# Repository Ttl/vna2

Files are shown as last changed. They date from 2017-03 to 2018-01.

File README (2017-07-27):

Second version of the homemade 30 MHZ - 6 GHz single receiver VNA design files.

First version: https://github.com/Ttl/vna

For more information see: http://hforsten.com/improved-homemade-vna.html

FPGA can be programmed with Openocd (http://openocd.org/). Scripts for programming the FPGA and SPI flash are in the "openocd" folder. Copy the bit file to openocd folder and use the command "openocd -f <script.cfg>" to program the board.

Before communication is possible with the board through USB, FT2232D EEPROM needs to be programmed. Port B needs to be changed in FIFO 245 mode. This can be done using FTDIs "ft-prog" tool.

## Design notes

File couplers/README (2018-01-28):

Resistive bridge coupler design files.

PCB Stackup: OSH park 4 layer process.

BOM: 
 3, http://www.mouser.fi/ProductDetail/Linx-Technologies/CONSMA003062/?qs=sGAEpiMZZMsgSGrx0WqTbDECK3OTA0n%2f
 1, http://www.mouser.fi/ProductDetail/EPCOS-TDK/B64290P0687X046/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
 3, http://www.mouser.fi/ProductDetail/Fair-Rite/5943000911/?qs=sGAEpiMZZMsuct6UGZJC7QQ6ZlEn2BkEKxrVH5WSvu8%3d
 2, http://www.mouser.fi/ProductDetail/Fair-Rite/5977000101/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

Resistors (See coupler_layout.png for positions):
 R1: 270
 R2: 50
 R3, R5: 36
 R4, R6: 39

Mount the resistors upside down to minimize parasitics.

Coaxial cable:
 RG405

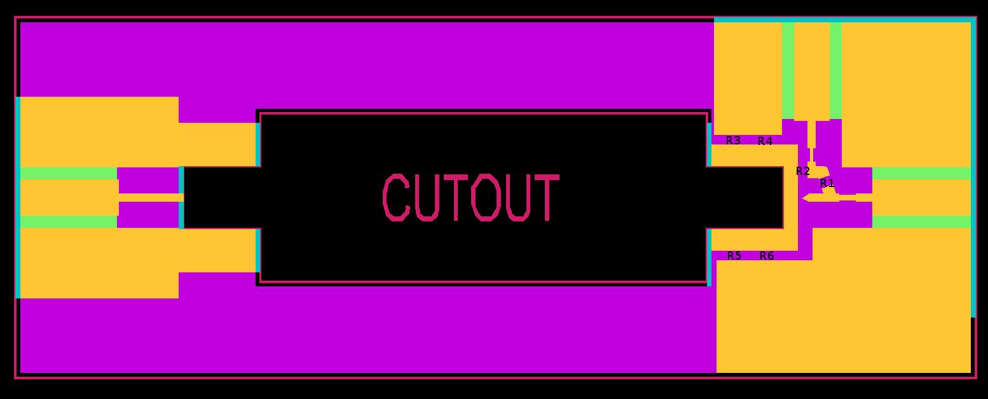
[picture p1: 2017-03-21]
couplers/coupler_layout.png

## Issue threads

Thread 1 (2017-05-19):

Do you have the BOM for VNA2

xfce, 2017-05-19:
Dear friend, do you have the BOM for VNA2, could you please upload here, thanks

Ttl, 2017-05-23:
You can use KiCad to generate BOM. I don't have a more detailed BOM than that at the moment.

Closed 2017-05-23.

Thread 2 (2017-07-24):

reproduction

drom, 2017-07-24:
Hi Henrik,
I am impressed by your VNA design, and want to made one for myself.
Do you recommend any improvements over what you have on Github?
You mentioned:
> The board had unfortunate resonance at 4.2 GHz, which I think comes from the poor grounding of the multiple ground planes. I think I'll need to order a new PCB with better grounding.

Do you plan making new revision of the PCB?

Ttl, 2017-07-24:
Better isolation is the biggest one. Source needs to be shielded and the whole thing needs a case. 5V rail should also have LDO after the buck converter to clean switching noise.

I'm not planning to make a version of the VNA at the moment. Maybe someday in future when I have motivation, but this version works fine enough for now.

The resonance refers to the TRL test board not VNA PCB. I have already made a new version of the test board which works fine.

jsr38, 2017-07-24:
Hey @drom  - I was thinking of building one too.  Sounds like straightforward changes.  I'm not planning on doing it right now but in a few months, when I get some time and my test gear back.  It would be good to share any design changes and progress.

ReinierG, 2017-07-24:
Same here. Time is the biggest issue. I would like to join you. I don't
mind the extra cost of better components (switches, shielding cans,
wider range VCO, ...)

Op 24-7-2017 om 22:45 schreef Jeremy Reeve:
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

oe2lsp, 2017-07-24:
that’s really great :)
I'm planing to build one as well. For shielding maybe for testing a simple Cu-FR4 shield is enough.
There are two improvements I'm thinking about, the first one is a shield around the generator at the top right. As well as some additional vias. I don't know if it is possible to hide a 5V LDO in the current shape, this would be nice so that everyone can use the same milled shield, if we find one.

drom, 2017-07-24:
Great to hear that I am not alone.
@Ttl agree that extra LDO is good.
@Ttl @oe2lsp I am all for more ground, more vias, Cu shielding. Don't mind bigger total PCB area, bit with better ground.
Milled RF shield, sound's expensive, but designing common bended RF shield sounds great

Ttl, 2017-07-25:
Similar sheet metal shielding as with the receiver is not really good enough unless it is soldered all the way such that there are absolutely no gaps at all but that makes prototyping very hard. Of course any shield is better than nothing, but even -100 dB leakage can be detect and a shield with gaps radiates better than that.

I was thinking of separating source and receiver to their own PCBs and connecting the RF with SMA cables. Physical separation is good for improving isolation. Unfortunately all the separate PCBs, shielding, cases and connectors really increase the cost, which is why I haven't had the motivation to make a new version yet.

Also some other improvements that I had in mind:

* Make IF amplifier gain variable (at least 20 dB). Amplifier gain drops at high frequencies and the signal power is much smaller than at low frequencies. Because of that ADC range is not utilized fully and the dynamic range is smaller.
* Replace ADA4932-1 IF amplifier with for example ADA4940-1. The current amplifier doesn't have rail-to-rail outputs and at the maximum output voltage it's close to the limit and causes distortion.
* Duplicate the receivers. One receiver for each port to improve the isolation. This also doubles the measurement speed.

vrytikov, 2017-07-25:
This is a great project. I am thinking of building one too. Would be nice to get pcb improvement.

ReinierG, 2017-07-25:
Hi Henrik,

What about using the recently introduced LMX2594? It has a 10 MHz- 15
GHz range and integrated LDOs. It will be difficult to make good
calibration standards. I've never had a use case for frequencies above
2.4 GHz, but the improved time domain transformation resolution would be
a big plus.
I agree with you about separating parts and connecting with SMA cables.
Modular design make things easier to make improvements. That's how I
started my VNA design (and did not yet finish it...)

Op 25-7-2017 om 07:24 schreef Henrik Forstén:
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

Ttl, 2017-07-25:
There are some issues with using LMX2594. First is that the chip costs 56€ compared to just 10€ for MAX2871. Second is that amplifier, switches and mixer needs to be replaced with 10 GHz capable ones. Those are going to cost also much more than the current ones. Total cost for 10 GHz version would be more than twice of the current version.

drom, 2017-07-25:
@Ttl agree, changing to LMX2594 (15GHz, $63) or even LMX2592 (10GHz, $35) will drive the rest of BOM up.

drom, 2017-07-25:
@Ttl how about replacing monster BGA FPGA package with something like Lattice IC40 Ultra Plus (in 48QFN package): file:///home/drom/work/github/drom/iCE40%20UltraPlus%20Family%20Data%20Sheet.pdf
It has 39 IO, 1Mibit SRAM, 8 MULT16,... etc.

Ttl, 2017-07-26:
ICE40 might have enough gates, but 39 IO pins is not enough. At least 60 pins are needed.

jsr38, 2017-07-26:
Perhaps if there is sufficient demand/activity there is a case for creating individual tickets concerning each proposed change or improvement.  Perhaps there is even a case for a cut-down version and a version where cost is less of a constraint.  Maybe that's a separate project altogether.

On the topic of shielding, would a milled shield be better for prototyping activities?  I don't have practical experience of such things but intuition tells me one should be able to remove and replace such a shield a large number of times if it were bolted.  I guess that would also require something like a fingerstrip to make good contiguous contact with the ground-plane on the board.  Although it sounds expensive perhaps prototyping of the shield could be done with a hobby 3d printer to validate the design before sending the job to a machinist then if there is sufficient interest split the cost of multiple shields to amortise the setup cost.

Actually, over the next few months I am working on modelling the properties of thermoplastic coated with graphite and then electroplated.  Maybe it's good enough to use for prototyping the shielding proper.  Maybe not.

kapil-iitk, 2019-04-18:
I have few to suggestions,
1. Integrate the coupler within the VNA PCB to save few bucks from 6+ 6=12 SMA connectors, and cables.
2. Use copper tape for the shilding. Also add insulator patch (such as OHP sheet) above the circuit (to isolate from the DC short). This may be efficient for the prototyping.

3. Any alternate of FPGA? to reduce the complexity and assembling inaccuracy.

blackberryer, 2019-11-25:
Hi Henrik,
You mentioned:
The resonance refers to the TRL test board not VNA PCB. I have already made a new version of the test board which works fine.

I guess your first version of the TRL test board didn't have enough vias. Is your new board improved grounding by punching enough holes?Is there any improvement elsewhere?

Closed 2017-07-24.

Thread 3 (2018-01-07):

Questions

reliable-bam, 2018-01-07:
First of all, amazing work! I would like to try my hand at cloning this project, and seeing what I can do to increase the frequency range and/or extend to 4 ports. I am in electronics reliability, and often need cheap relatively-accurate RF bench test and in situ (environmental stress) test equipment in the L, S, X, and K bands. Due to business accounting, it's often easier to build engineering boards rather than slug through the arduous capital acquisition steps for equipment that is far more than what I need. My most recent activity requires a stable differential S-par characterization pre/post stress up to 26.5GHz. Obviously I'm not going to get that all in one shot/design/project, and will require an iterative and more complex (and higher part count) solution. This would try to rival the basic capabilities of something like the 5242 4-port PNAs from Keysight/Agilent. If this could be done at 5-10% of the cost, that would be a phenomenal achievement. I would then probably quit my job and make PNA's for a living :-) I think a more reasonable goal would be to target something functional through X band. Any block diagram / recommendations on where to focus for this project would be greatly appreciated. One idea I was thinking about was replacing the baluns with diplexers or filters. This would be much more lossy (particularly in the cross over region) and noisy, but might start me on the path of combining dedicated blocks to handle lower and higher frequency bands without having to source extremely broad band components. As a side note, I'm also aware that calibrating such a beast will be a wholly new project (perhaps a second switched calibration board). I do fully admit that the convenience of Agilent Ecal may be giving me a false impression of how achievable this endevor is.

Also, I had some questions about possible ways to improve performance / noise on your mark-2 VNA design. It seems to me that there is a lot of unused space on the bottom layer. Would it be more efficient to move components that generate noise interference such as receivers/switches to the backside? My thinking is that the internal ground planes should provide some free receiver shielding from the source components and FPGA. Also, this might shorten some of your lines, or place via rows in between some signal lines that are the worst cross-talk offenders (if known). Clearly this would make soldering more of a challenge, but the benefits might outweigh the assy challenges. I was also wondering if you couldn't extend the edge of the board and place the couplers on it? You could pull back the copper grounds for better isolation, and it would cut down on the connectors. The ferrite bead sub assembly is hand solder regardless, and it's one less setup / board fab cost.

Thank you for putting so much effort into making this concept such a successful reality. I'm new to GitHub, and just thrilled that you are sharing the fruits of your labor to perpetuate greater access to advanced analysis tools.

Ttl, 2018-01-09:
It's usually better to use switches and separate circuits for each band than to try designing one very wideband circuit. I don't think there is any place for a diplexer in VNA since it can be replaced with just a switch because there is only one frequency in the circuit at a time.

I wouldn't put components on the back side. It's hard to solder and doesn't improve isolation that much. Better to use individually shielded compartments or separate PCBs.

Connectors don't cost much and it's cheaper to use separate couplers when they are identical than make one big PCB with multiple copies of couplers.

Also take look at #2 for some other possible improvements.

Closed 2018-01-09.

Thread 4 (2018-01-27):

Coupler BOM do not match photos on the blog

micovo, 2018-01-27:
Hi Henrik,
I'm little confused about the difference between coupler BOM on Github and photos on your blog.
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
What I see on the photo is 3pcs of 5943000911, 2pcs of 5977000101 and 1pcs of B64290P0687X046.
On the BOM is 2pcs of 5943000911 and 3pcs of 5977000101.
Did You make a change in assembly without posting it on your blog or is it mistake in the BOM?
Thanks, Michal

Ttl, 2018-01-28:
You're right. I fixed the BOM.

The exact choice of ferrite beads doesn't seem too important. I ran out of some beads and put some different ones in few couplers, but I didn't really notice any significant performance differences.

Closed 2018-01-28.

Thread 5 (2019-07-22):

I and Q data to S parameters algorithm

vijaykarthik123, 2019-07-22:
Hi Henrik,

Great job on the VNA design! I am trying to correlate between an FMCW radar and a VNA. In the FMCW radar, the ADC digitizes the IF signal into I and Q samples.

In your VNA design, the ADC samples the IF signal into I and Q samples. How did you convert the low frequency IF data into RF S parameters? I am reading your `sparam.py` file and in `iq_to_sparam()` there is a formula and algorithm which I am not able to grasp.

Thanks for your help on this.

Ttl, 2019-07-23:
VNA mixes the RF to low frequency IF (few MHz) which is sampled by the ADC and is then IQ mixed inside the FPGA in the digital domain. It needs to be done digitally because analog IQ mixing accuracy isn't high enough.

S-parameters from IQ samples is just normal ratios from the S-parameter definitions. For example S11 is reflected power measurement divided by transmitted power measurement. `sw_correction` in `iq_to_sparam()` is switch correction. It's a part of 8-term VNA calibration.

Closed 2019-07-23.

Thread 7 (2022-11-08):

Cheap shielding

mordae, 2022-11-08:
Hi, thanks for sharing!

I have read your articles and hopefully one day I'll be able to replicate your work.

Wouldn't it be possible to implement shielding cheaper than custom milling / bending with the help of 3D printed covers coated with EMI-shielding copper-based spray paint? There are several products specifically for this use and I have seem them claim about 60 dB attenuation for 50 µm coating.

reliable-bam, 2022-11-08:
Be careful with what you spray over the top of PWBs. Any coating can reduce
switch isolation and introduce coupling. Especially as circuits are in
close proximity.

On Tue, Nov 8, 2022, 4:58 AM Jan Hamal Dvořák ***@***.***>
wrote:

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

mordae, 2022-11-14:
@reliable-bam: I am not sure I follow. I was talking about 3D printing covers (such as those that are usually made from bent metals and soldered on the board - over the components) and coating those. They would have to be mounted using screws instead of being soldered directly, though.

Closed 2024-10-01.

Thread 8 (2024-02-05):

Impedance Problems

kleeneee, 2024-02-05:
Thanks for sharing! From the PCB, I have got the impedances in bridge parts are different and  not equal to 50ohm. Could you please explain the reasons for me? Thank you!

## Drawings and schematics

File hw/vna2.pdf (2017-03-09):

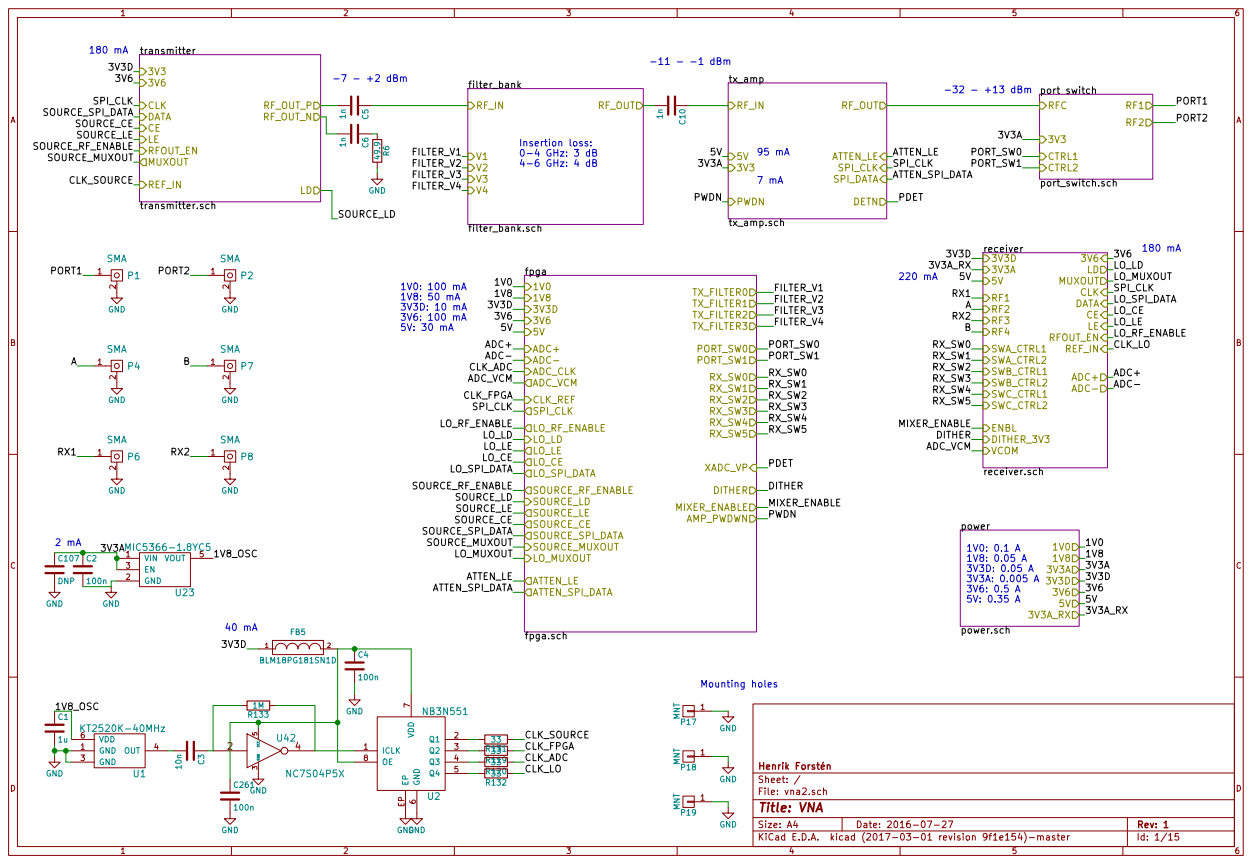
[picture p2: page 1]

File: vna2.sch Sheet: / Henrik Forstén

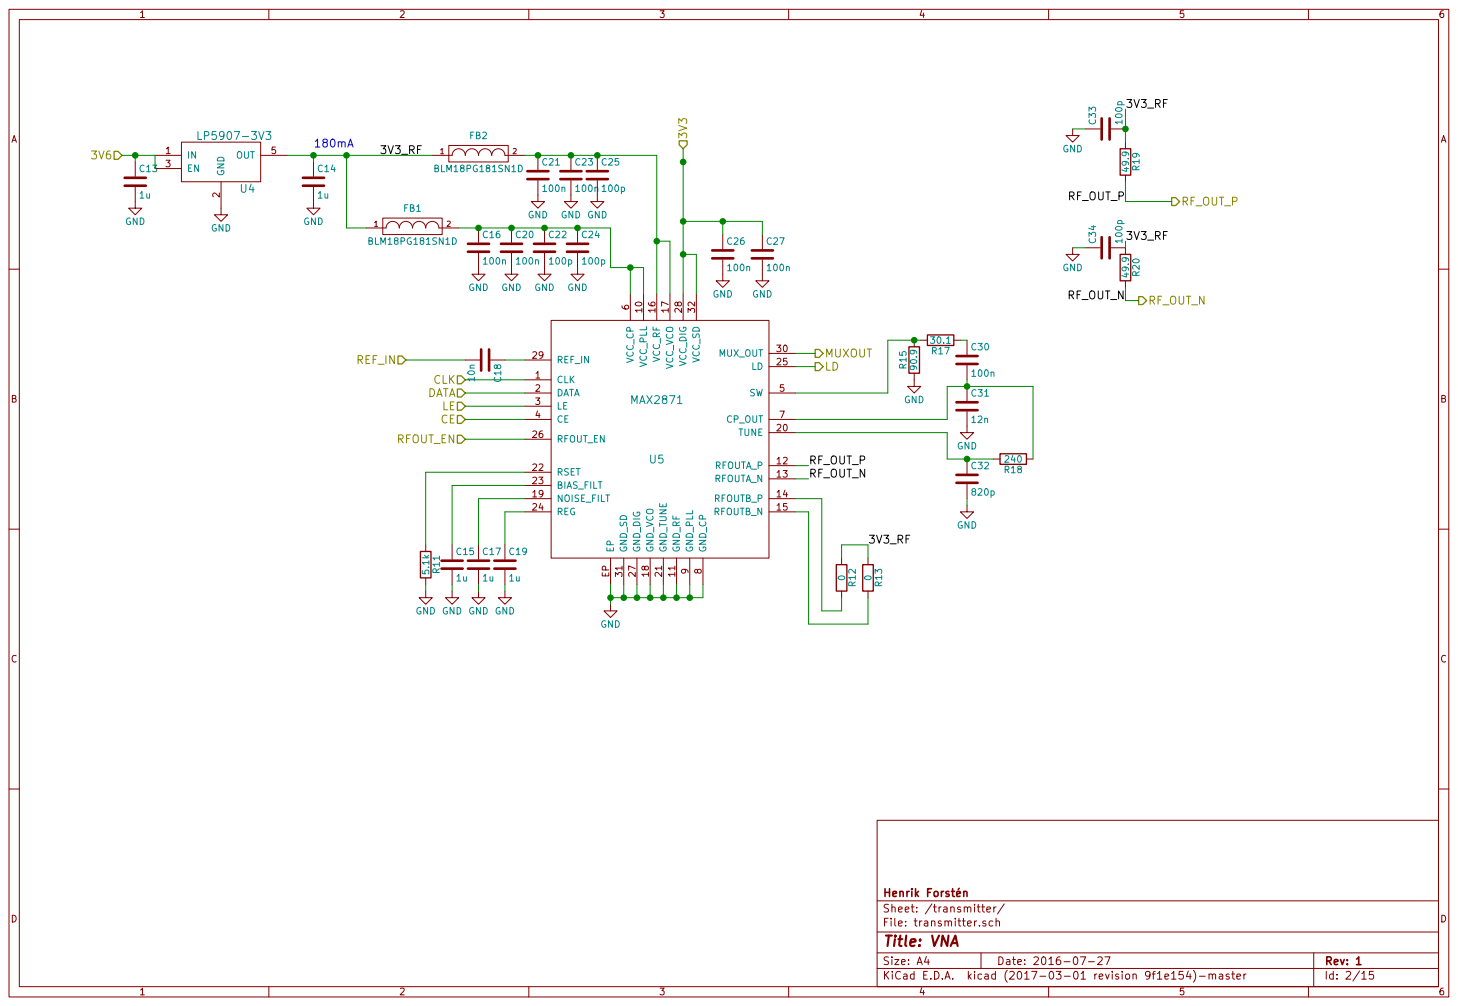
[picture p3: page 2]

100n GND GND GND GND GND

100n 5.1k R11 GND GND GND GND

File: transmitter.sch Sheet: /transmitter/ Henrik Forstén

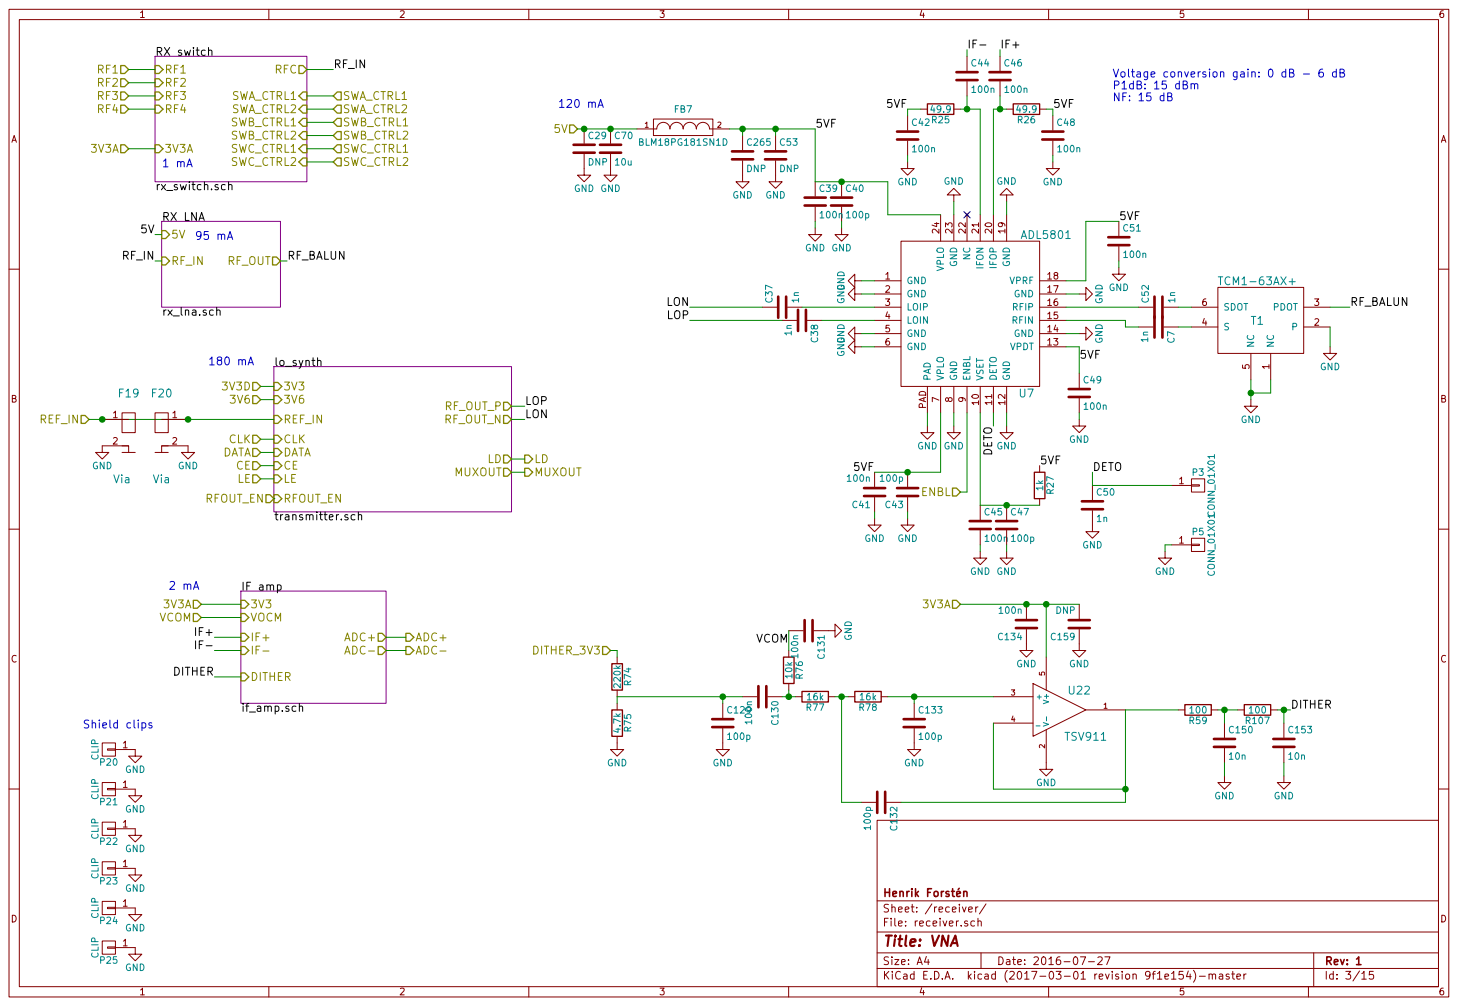
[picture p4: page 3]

9 VSET 10 IFOP 20 DETO 11 IFON 21 GND 12 NC 22 VPDT 13 GND 23 GND 14 VPLO 24 RFIN 15 RFIP 16 GND 17 VPRF 18 GND 19 PAD PADU7ADL5801 GND GND C37 1n

File: receiver.sch Sheet: /receiver/ Henrik Forstén

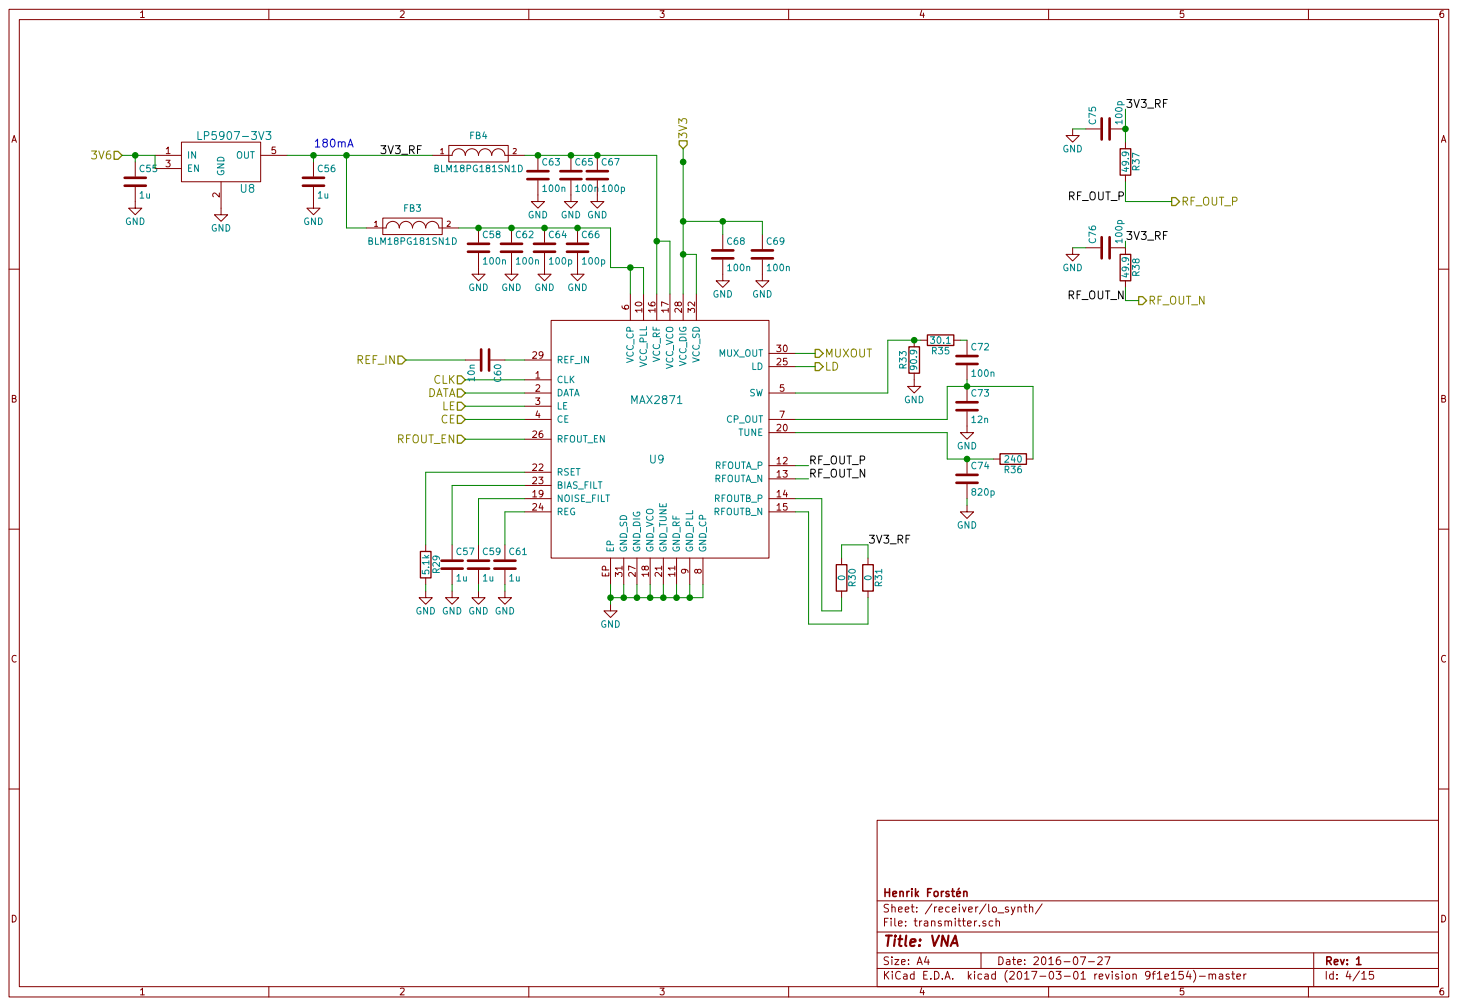
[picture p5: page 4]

100n GND GND GND GND GND

100n 5.1k R29 GND GND GND GND

Henrik Forstén
File: transmitter.sch Sheet: /receiver/lo_synth/
Id: 4/15 Title: VNA

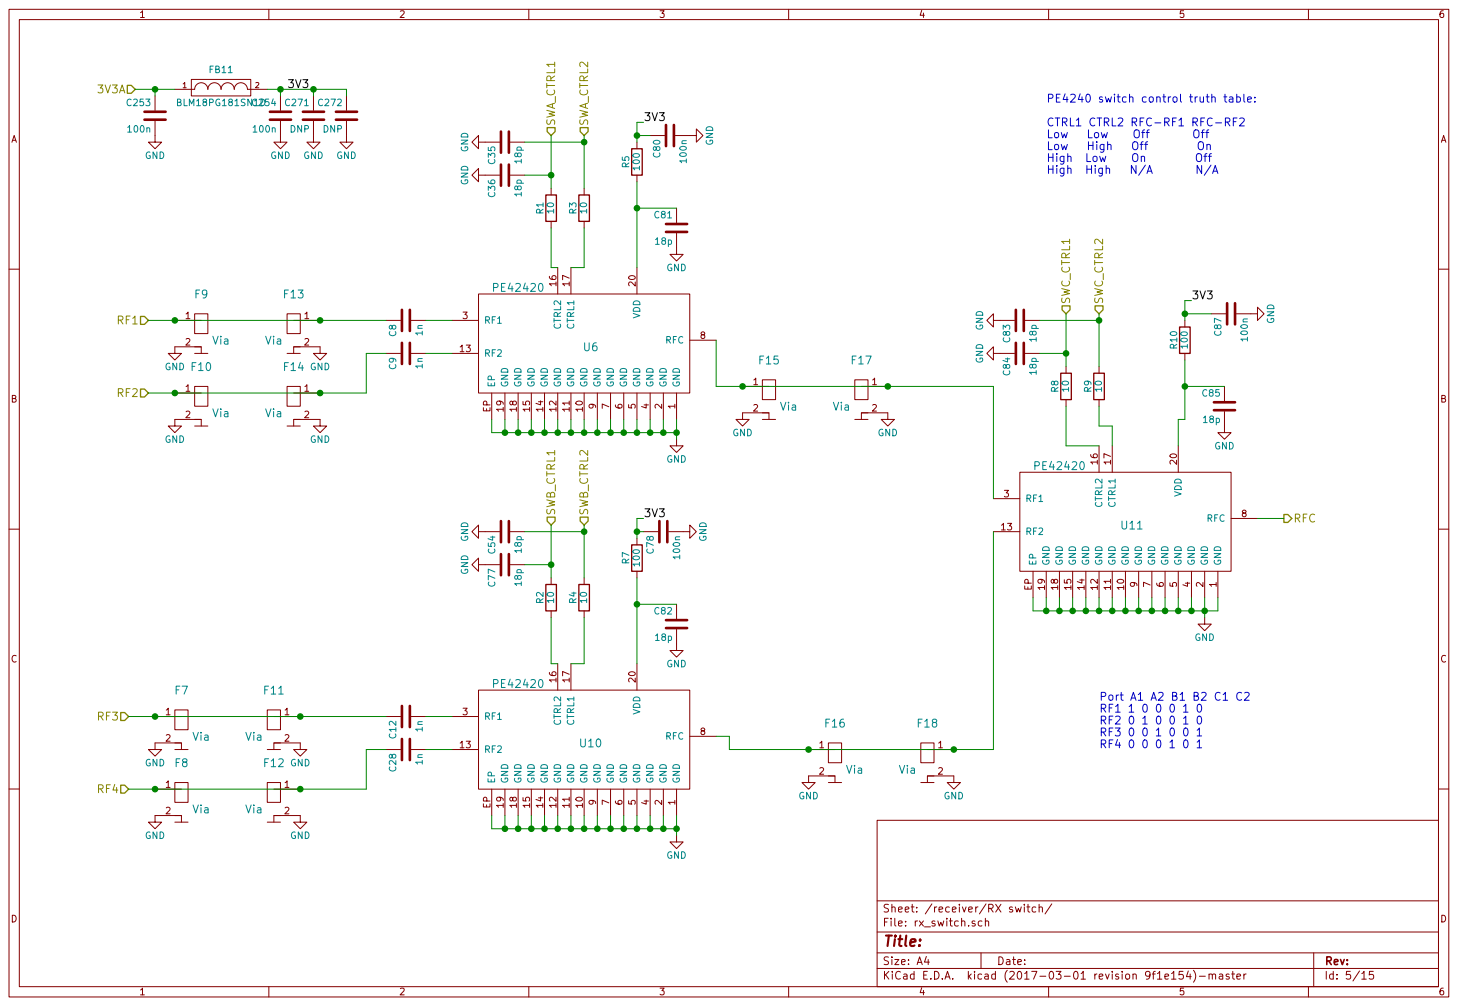
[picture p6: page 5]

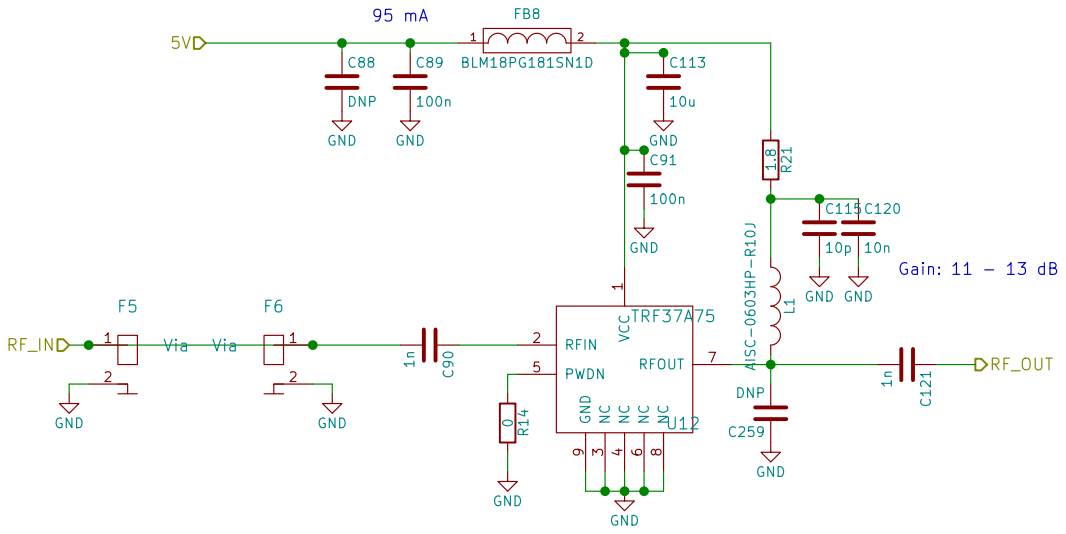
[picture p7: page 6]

File: rx_lna.sch Sheet: /receiver/RX LNA/ VCC

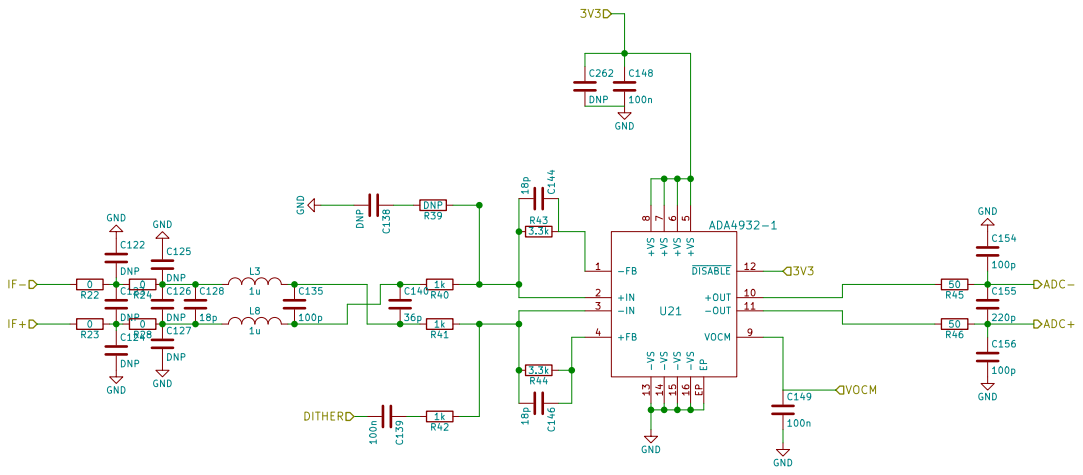
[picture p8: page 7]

C125 DNP C127 DNP GND GND

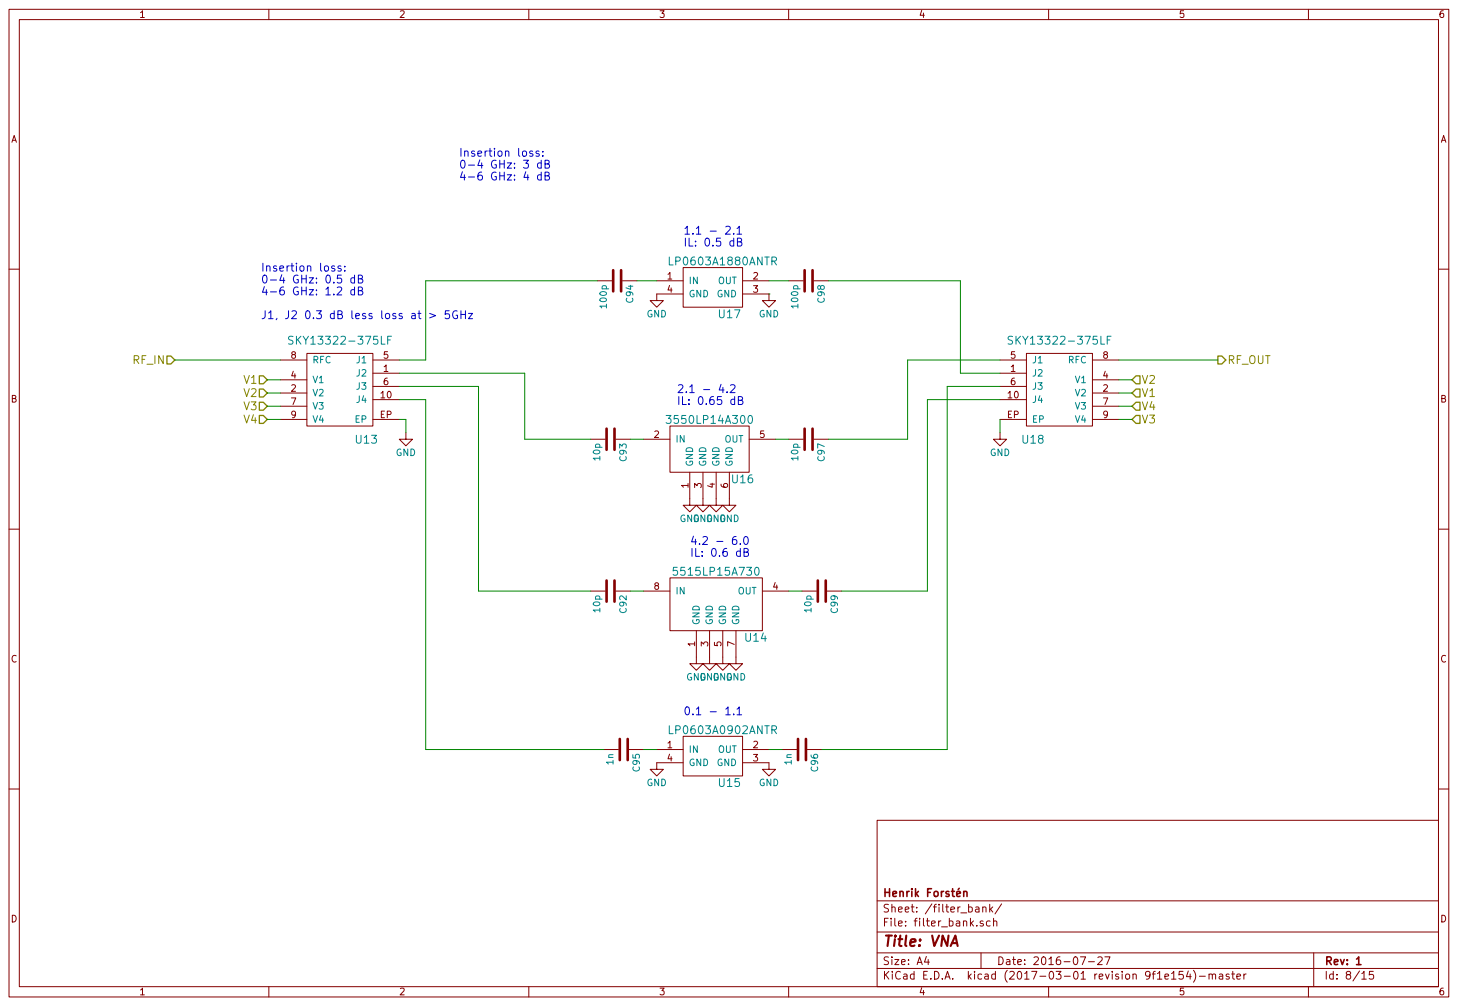
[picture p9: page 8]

Insertion loss: 0-4 GHz: 3 dB
4-6 GHz: 4 dB

Insertion loss: 0-4 GHz: 0.5 dB
4-6 GHz: 1.2 dB
J1, J2 0.3 dB less loss at > 5GHz

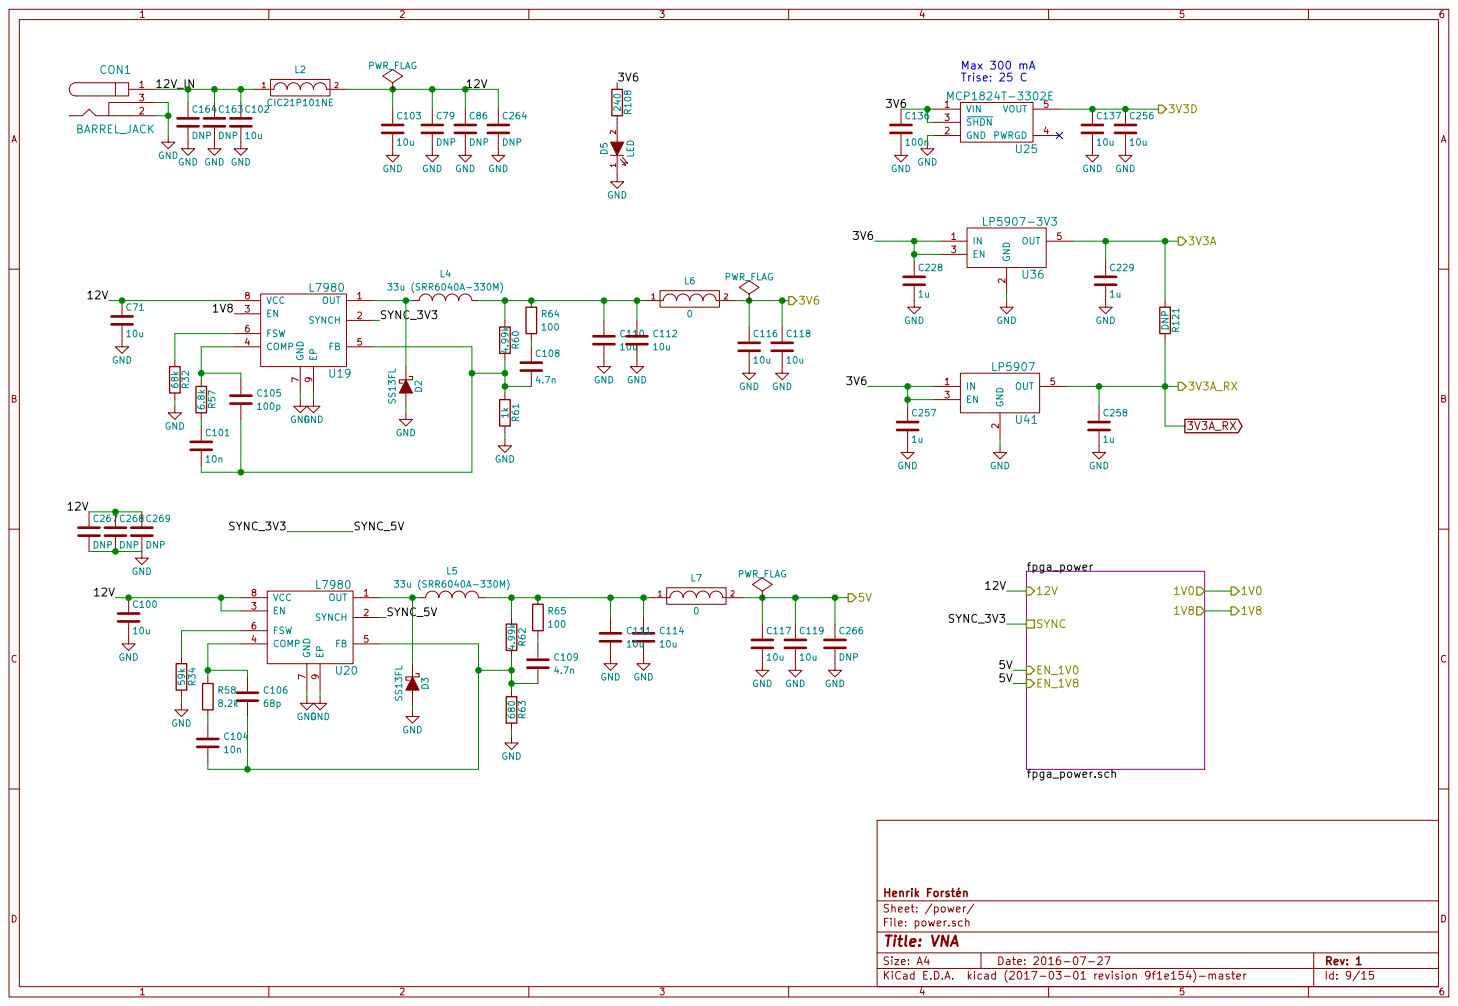
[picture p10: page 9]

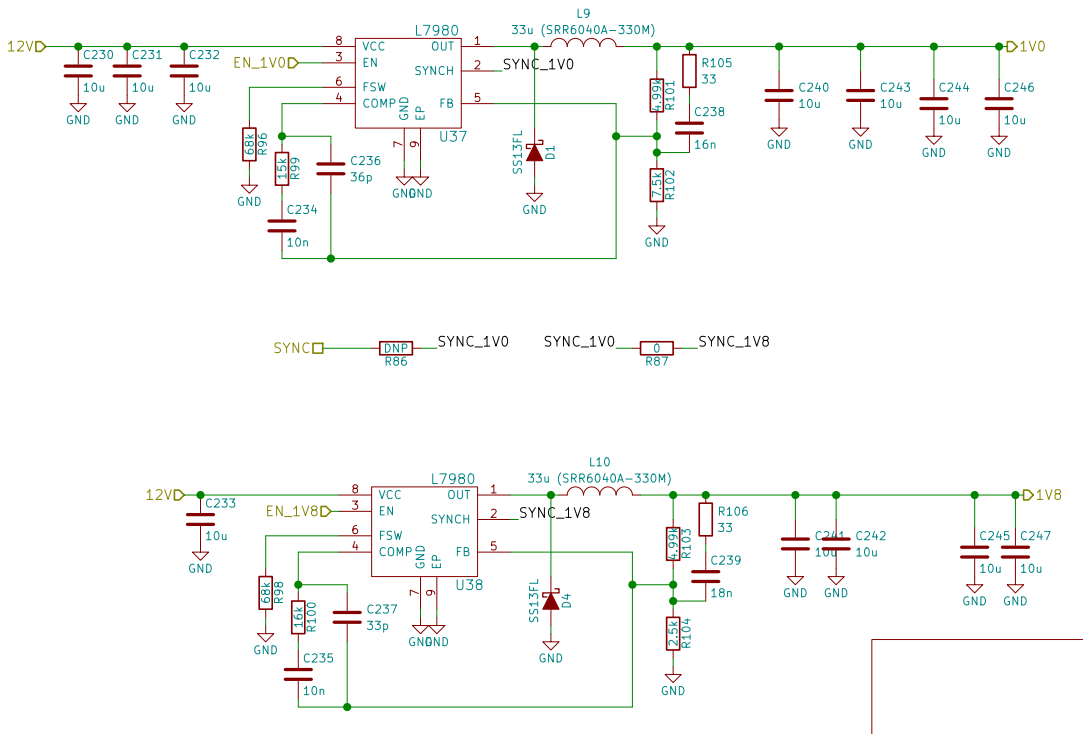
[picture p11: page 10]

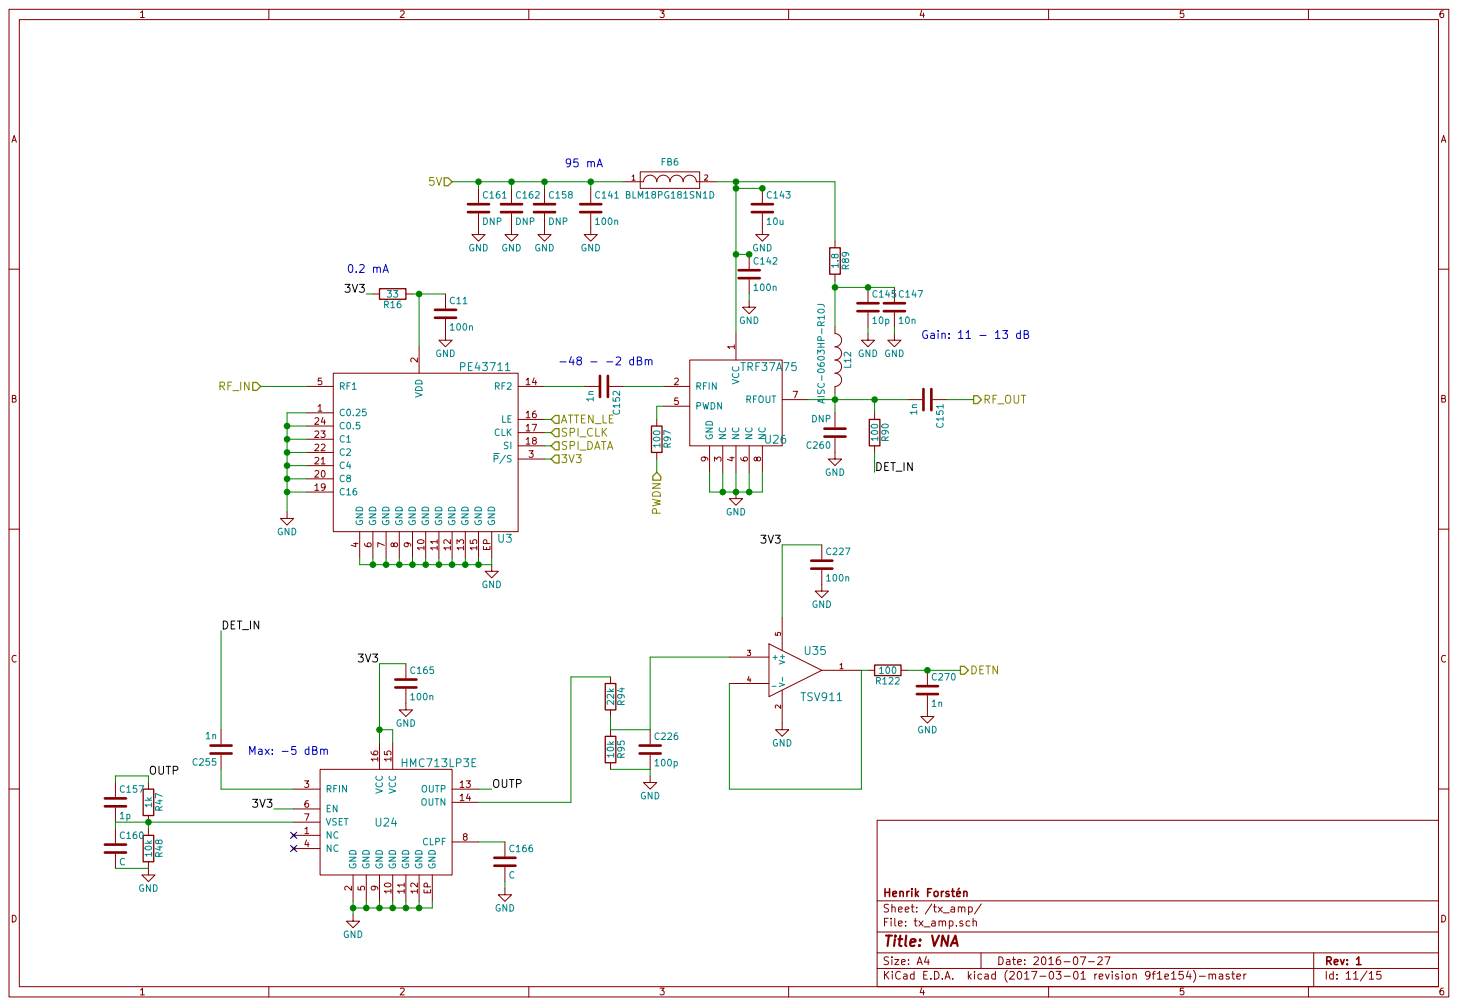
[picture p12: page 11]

9 GND 10 C8 20 GND 11 C4 21 GND 12 C2 22 GND 13 C1 23 RF2 14 C0.5 24 GND 15

9 GND 10 GND 11 GND 12 OUTP 13 OUTN 14 VCC 15 VCC 16 GND EP U24 HMC713LP3E

5 EN 6 VSET 7 CLPF 8 GND

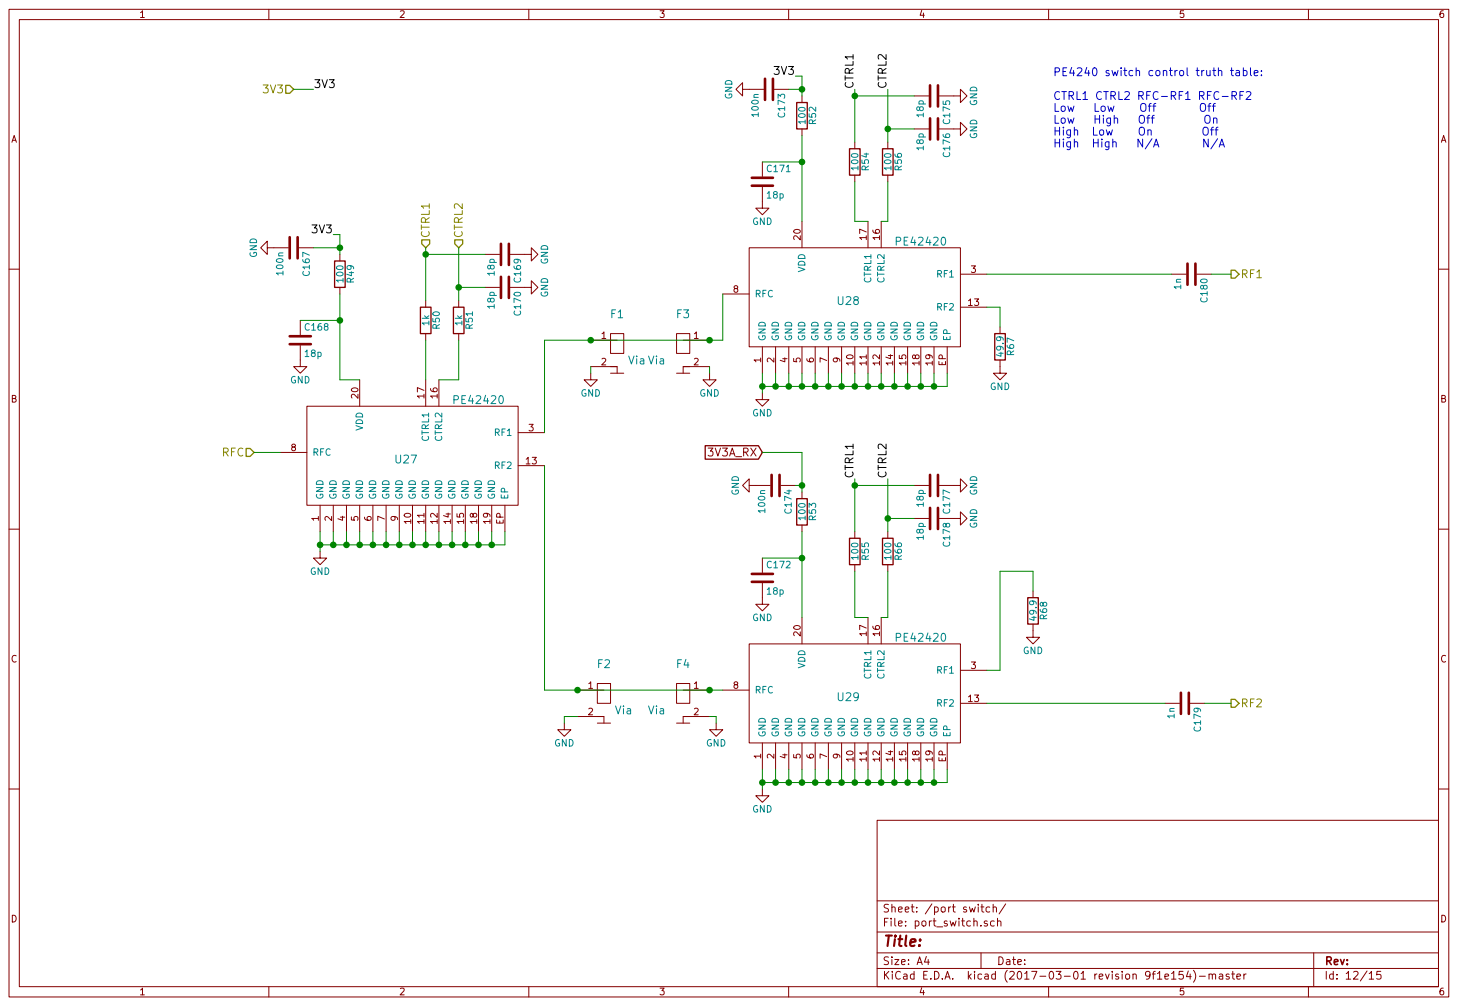
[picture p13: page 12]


adc adc.sch ADC+

Power supply ramp time: 0.2 ms - 50 ms
Internal reference Quiescent current 1V0: 97 mA

Power-on current 1V0: Iq + 180 mA


TMS D0 D1 D2 D3 D4 D5 D6 D7 RXF# TXE# RD# WR

9 SI/WUA 10 ADBUS4 20 BCBUS0/RXF# 30 BDBUS0 40 ACBUS3 11 ADBUS3/TMS 21 VCCIOB 31 PWREN# 41 ACBUS2 12 ADBUS2/TDO 22 BDBUS7 32 VCC 42 ACBUS1 13 ADBUS1/TDI 23 BDBUS6 33 XTIN 43 VCCIOA 14 ADBUS0/TCK 24 GND 34 XTOUT 44 ACBUS0 15 GND 25 BDBUS5 35 AGND 45 ADBUS7 16 SI/WUB 26 BDBUS4 36 AVCC 46 ADBUS6 17 BCBUS3/WR 27 BDBUS3 37 TEST 47 GND 18 BCBUS2/RD# 28 BDBUS2 38 EECS 48 ADBUS5 19 BCBUS1/TXE# 29 BDBUS1 39 U33 FT2232D


8 CLK 9 SHDN 10 OGND 20 SENSE 30 OE 11 OVDD 21 D0 12 D8 22 VDD 32 D1 13 D9 23 D2 14 D10 24 D3 15 D11 25 D4 16 D12 26 D5 17 D13 27 D6 18 OF 28 D7 19 MODE 29 U34

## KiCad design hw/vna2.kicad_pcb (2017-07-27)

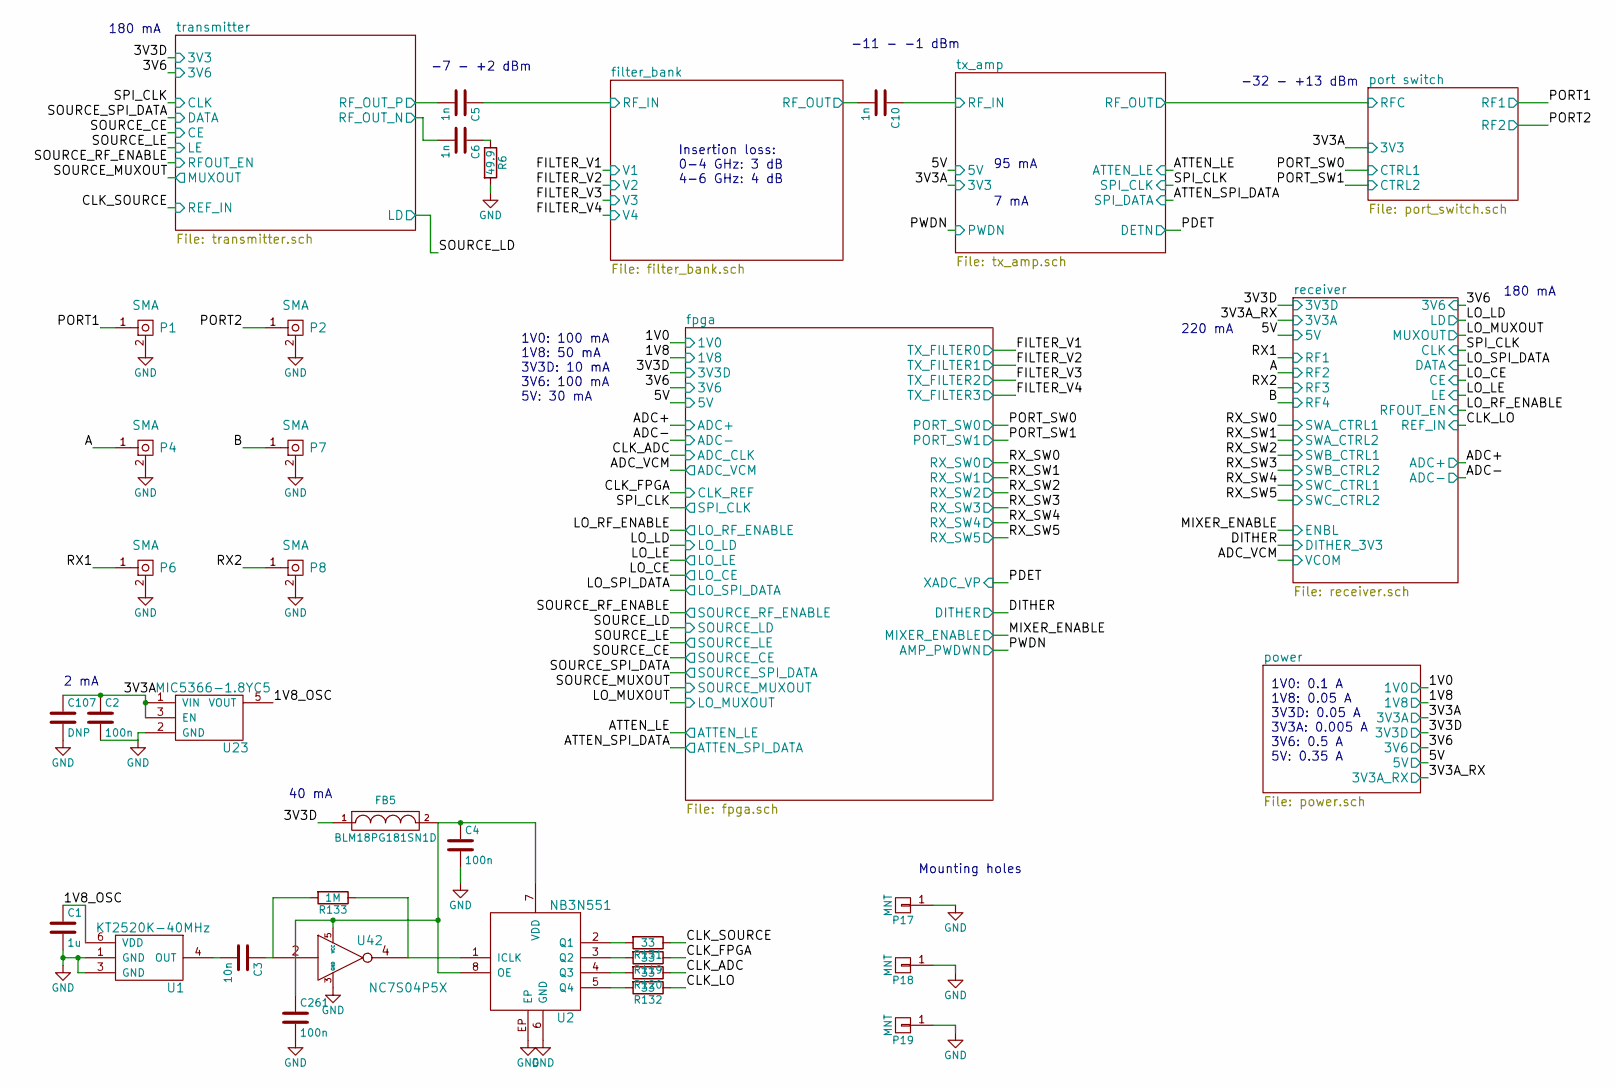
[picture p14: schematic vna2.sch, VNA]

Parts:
C1: 1u; C_0402b
C2, C4, C261: 100n; C_0402b
C3: 10n; C_0402b
C5, C6, C10: 1n; C_0402b
C107: DNP; C_0805b
FB5: BLM18PG181SN1D; C_0603b
P1, P2, P4, P6, P7, P8: SMA; CONSMA003.062
P17, P18, P19: MNT; MountingHole_3.2mm_M3_Pad_Via_mod
R6: 49.9; R_0402b
R119, R120, R131, R132: 33; R_0402b
R133: 1M; R_0402b
U1: KT2520K-40MHz; KT2520K
U2: NB3N551; DFN-8
U23: MIC5366-1.8YC5; SOT-353
U42: NC7S04P5X; SOT-353

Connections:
/1V8_OSC: C1.1, U1.6 (VDD), U23.5 (VOUT)
/3V3A: C2.1, C107.1, U23.1 (VIN), U23.3 (EN); also elsewhere on the board
/3V3D: FB5.1; also elsewhere on the board
/A: P4.1; also elsewhere on the board
/B: P7.1; also elsewhere on the board
/CLK_ADC: R120.1; also elsewhere on the board
/CLK_FPGA: R119.1; also elsewhere on the board
/CLK_LO: R132.1; also elsewhere on the board
/CLK_SOURCE: R131.1; also elsewhere on the board
/PORT1: P1.1; also elsewhere on the board
/PORT2: P2.1; also elsewhere on the board
/RX1: P6.1; also elsewhere on the board
/RX2: P8.1; also elsewhere on the board
/filter_bank/RF_IN: C5.1; also elsewhere on the board
/filter_bank/RF_OUT: C10.2; also elsewhere on the board
/transmitter/RF_OUT_N: C6.2; also elsewhere on the board
/transmitter/RF_OUT_P: C5.2; also elsewhere on the board
/tx_amp/RF_IN: C10.1; also elsewhere on the board
GND: C1.2, C2.2, C4.2, C107.2, C261.2, P1.2, P2.2, P4.2, P6.2, P7.2, P8.2, P17.1, P18.1, P19.1, R6.2, U1.1 (GND), U1.3 (GND), U2.6 (GND), U2.EP, U23.2 (GND), U42.3 (GND); also elsewhere on the board
unnamed: C3.1, R133.2, U42.2
unnamed: C3.2, U1.4 (OUT)
unnamed: C6.1, R6.1
unnamed: C4.1, C261.1, FB5.2, U2.7 (VDD), U2.8 (OE), U42.5 (VCC)
unnamed: R119.2, U2.3 (Q2)
unnamed: R120.2, U2.4 (Q3)
unnamed: R131.2, U2.2 (Q1)
unnamed: R132.2, U2.5 (Q4)
unnamed: R133.1, U2.1 (ICLK), U42.4

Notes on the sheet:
2 mA
Insertion loss: 0-4 GHz: 3 dB 4-6 GHz: 4 dB
-7 - +2 dBm
-11 - -1 dBm
-32 - +13 dBm
180 mA
220 mA
95 mA
7 mA
1V0: 100 mA 1V8: 50 mA 3V3D: 10 mA 3V6: 100 mA 5V: 30 mA
1V0: 0.1 A 1V8: 0.05 A 3V3D: 0.05 A 3V3A: 0.005 A 3V6: 0.5 A 5V: 0.35 A
Mounting holes
40 mA

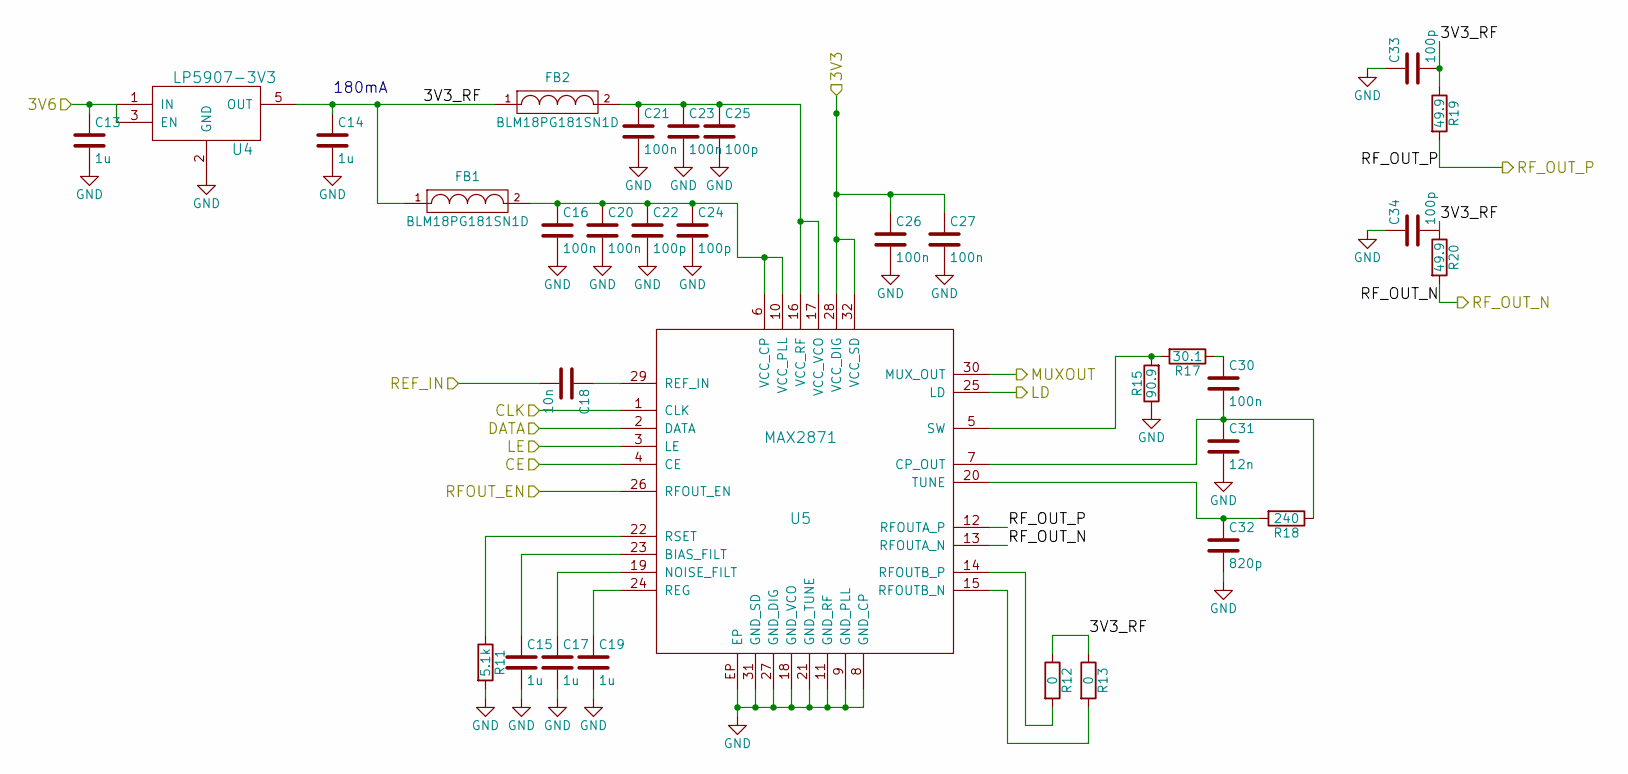
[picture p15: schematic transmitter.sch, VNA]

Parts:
C13, C14, C15, C17, C19: 1u; C_0603b
C16, C20, C21, C23, C26, C27, C30: 100n; C_0402b
C18: 10n; C_0402b
C22, C24, C25, C33, C34: 100p; C_0402b
C31: 12n; C_0402b
C32: 820p; C_0402b
FB1, FB2: BLM18PG181SN1D; C_0603b
R11: 5.1k; R_0402b
R12, R13: 0; R_0402b
R15: 90.9; R_0402b
R17: 30.1; R_0402b
R18: 240; R_0402b
R19, R20: 49.9; R_0402b
U4: LP5907-3V3; SOT-23-5
U5: MAX2871; TQFN-32

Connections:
/3V3D: C26.1, C27.1, U5.28 (VCC_DIG), U5.32 (VCC_SD); also elsewhere on the board
/3V6: C13.1, U4.1 (IN), U4.3 (EN); also elsewhere on the board
/CLK_SOURCE: C18.2; also elsewhere on the board
/SOURCE_CE: U5.4 (CE); also elsewhere on the board
/SOURCE_LD: U5.25 (LD); also elsewhere on the board
/SOURCE_LE: U5.3 (LE); also elsewhere on the board
/SOURCE_MUXOUT: U5.30 (MUX_OUT); also elsewhere on the board
/SOURCE_RF_ENABLE: U5.26 (RFOUT_EN); also elsewhere on the board
/SOURCE_SPI_DATA: U5.2 (DATA); also elsewhere on the board
/SPI_CLK: U5.1 (CLK); also elsewhere on the board
/transmitter/3V3_RF: C14.1, C33.2, C34.2, FB1.1, FB2.1, R12.1, R13.1, R19.1, R20.1, U4.5 (OUT)
/transmitter/RF_OUT_N: R20.2, U5.13 (RFOUTA_N); also elsewhere on the board
/transmitter/RF_OUT_P: R19.2, U5.12 (RFOUTA_P); also elsewhere on the board
GND: C13.2, C14.2, C15.2, C16.2, C17.2, C19.2, C20.2, C21.2, C22.2, C23.2, C24.2, C25.2, C26.2, C27.2, C31.2, C32.2, C33.1, C34.1, R11.2, R15.1, U4.2 (GND), U5.8 (GND_CP), U5.9 (GND_PLL), U5.11 (GND_RF), U5.18 (GND_VCO), U5.21 (GND_TUNE), U5.27 (GND_DIG), U5.31 (GND_SD), U5.EP; also elsewhere on the board
unnamed: C15.1, U5.23 (BIAS_FILT)
unnamed: C16.1, C20.1, C22.1, C24.1, FB1.2, U5.6 (VCC_CP), U5.10 (VCC_PLL)
unnamed: C17.1, U5.19 (NOISE_FILT)
unnamed: C18.1, U5.29 (REF_IN)
unnamed: C19.1, U5.24 (REG)
unnamed: C21.1, C23.1, C25.1, FB2.2, U5.16 (VCC_RF), U5.17 (VCC_VCO)
unnamed: C30.1, R17.1
unnamed: C30.2, C31.1, R18.1, U5.7 (CP_OUT)
unnamed: C32.1, R18.2, U5.20 (TUNE)
unnamed: R11.1, U5.22 (RSET)
unnamed: R12.2, U5.14 (RFOUTB_P)
unnamed: R13.2, U5.15 (RFOUTB_N)
unnamed: R15.2, R17.2, U5.5 (SW)

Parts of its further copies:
C55, C56, C57, C59, C61: 1u; C_0603b
C58, C62, C63, C65, C68, C69, C72: 100n; C_0402b
C60: 10n; C_0402b
C64, C66, C67, C75, C76: 100p; C_0402b
C73: 12n; C_0402b
C74: 820p; C_0402b
FB3, FB4: BLM18PG181SN1D; C_0603b
R29: 5.1k; R_0402b
R30, R31: 0; R_0402b
R33: 90.9; R_0402b
R35: 30.1; R_0402b
R36: 240; R_0402b
R37, R38: 49.9; R_0402b
U8: LP5907-3V3; SOT-23-5
U9: MAX2871; TQFN-32

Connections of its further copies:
/3V3D: C68.1, C69.1, U9.28 (VCC_DIG), U9.32 (VCC_SD); also elsewhere on the board
/3V6: C55.1, U8.1 (IN), U8.3 (EN); also elsewhere on the board
/CLK_LO: C60.2; also elsewhere on the board
/LO_CE: U9.4 (CE); also elsewhere on the board
/LO_LD: U9.25 (LD); also elsewhere on the board
/LO_LE: U9.3 (LE); also elsewhere on the board
/LO_MUXOUT: U9.30 (MUX_OUT); also elsewhere on the board
/LO_RF_ENABLE: U9.26 (RFOUT_EN); also elsewhere on the board
/LO_SPI_DATA: U9.2 (DATA); also elsewhere on the board
/SPI_CLK: U9.1 (CLK); also elsewhere on the board
/receiver/LON: R38.2, U9.13 (RFOUTA_N); also elsewhere on the board
/receiver/LOP: R37.2, U9.12 (RFOUTA_P); also elsewhere on the board
/receiver/lo_synth/3V3_RF: C56.1, C75.2, C76.2, FB3.1, FB4.1, R30.1, R31.1, R37.1, R38.1, U8.5 (OUT)
GND: C55.2, C56.2, C57.2, C58.2, C59.2, C61.2, C62.2, C63.2, C64.2, C65.2, C66.2, C67.2, C68.2, C69.2, C73.2, C74.2, C75.1, C76.1, R29.2, R33.1, U8.2 (GND), U9.8 (GND_CP), U9.9 (GND_PLL), U9.11 (GND_RF), U9.18 (GND_VCO), U9.21 (GND_TUNE), U9.27 (GND_DIG), U9.31 (GND_SD), U9.EP; also elsewhere on the board
unnamed: C57.1, U9.23 (BIAS_FILT)
unnamed: C58.1, C62.1, C64.1, C66.1, FB3.2, U9.6 (VCC_CP), U9.10 (VCC_PLL)
unnamed: C59.1, U9.19 (NOISE_FILT)
unnamed: C60.1, U9.29 (REF_IN)
unnamed: C61.1, U9.24 (REG)
unnamed: C63.1, C65.1, C67.1, FB4.2, U9.16 (VCC_RF), U9.17 (VCC_VCO)
unnamed: C72.1, R35.1
unnamed: C72.2, C73.1, R36.1, U9.7 (CP_OUT)
unnamed: C74.1, R36.2, U9.20 (TUNE)
unnamed: R29.1, U9.22 (RSET)
unnamed: R30.2, U9.14 (RFOUTB_P)
unnamed: R31.2, U9.15 (RFOUTB_N)
unnamed: R33.2, R35.2, U9.5 (SW)

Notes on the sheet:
180mA

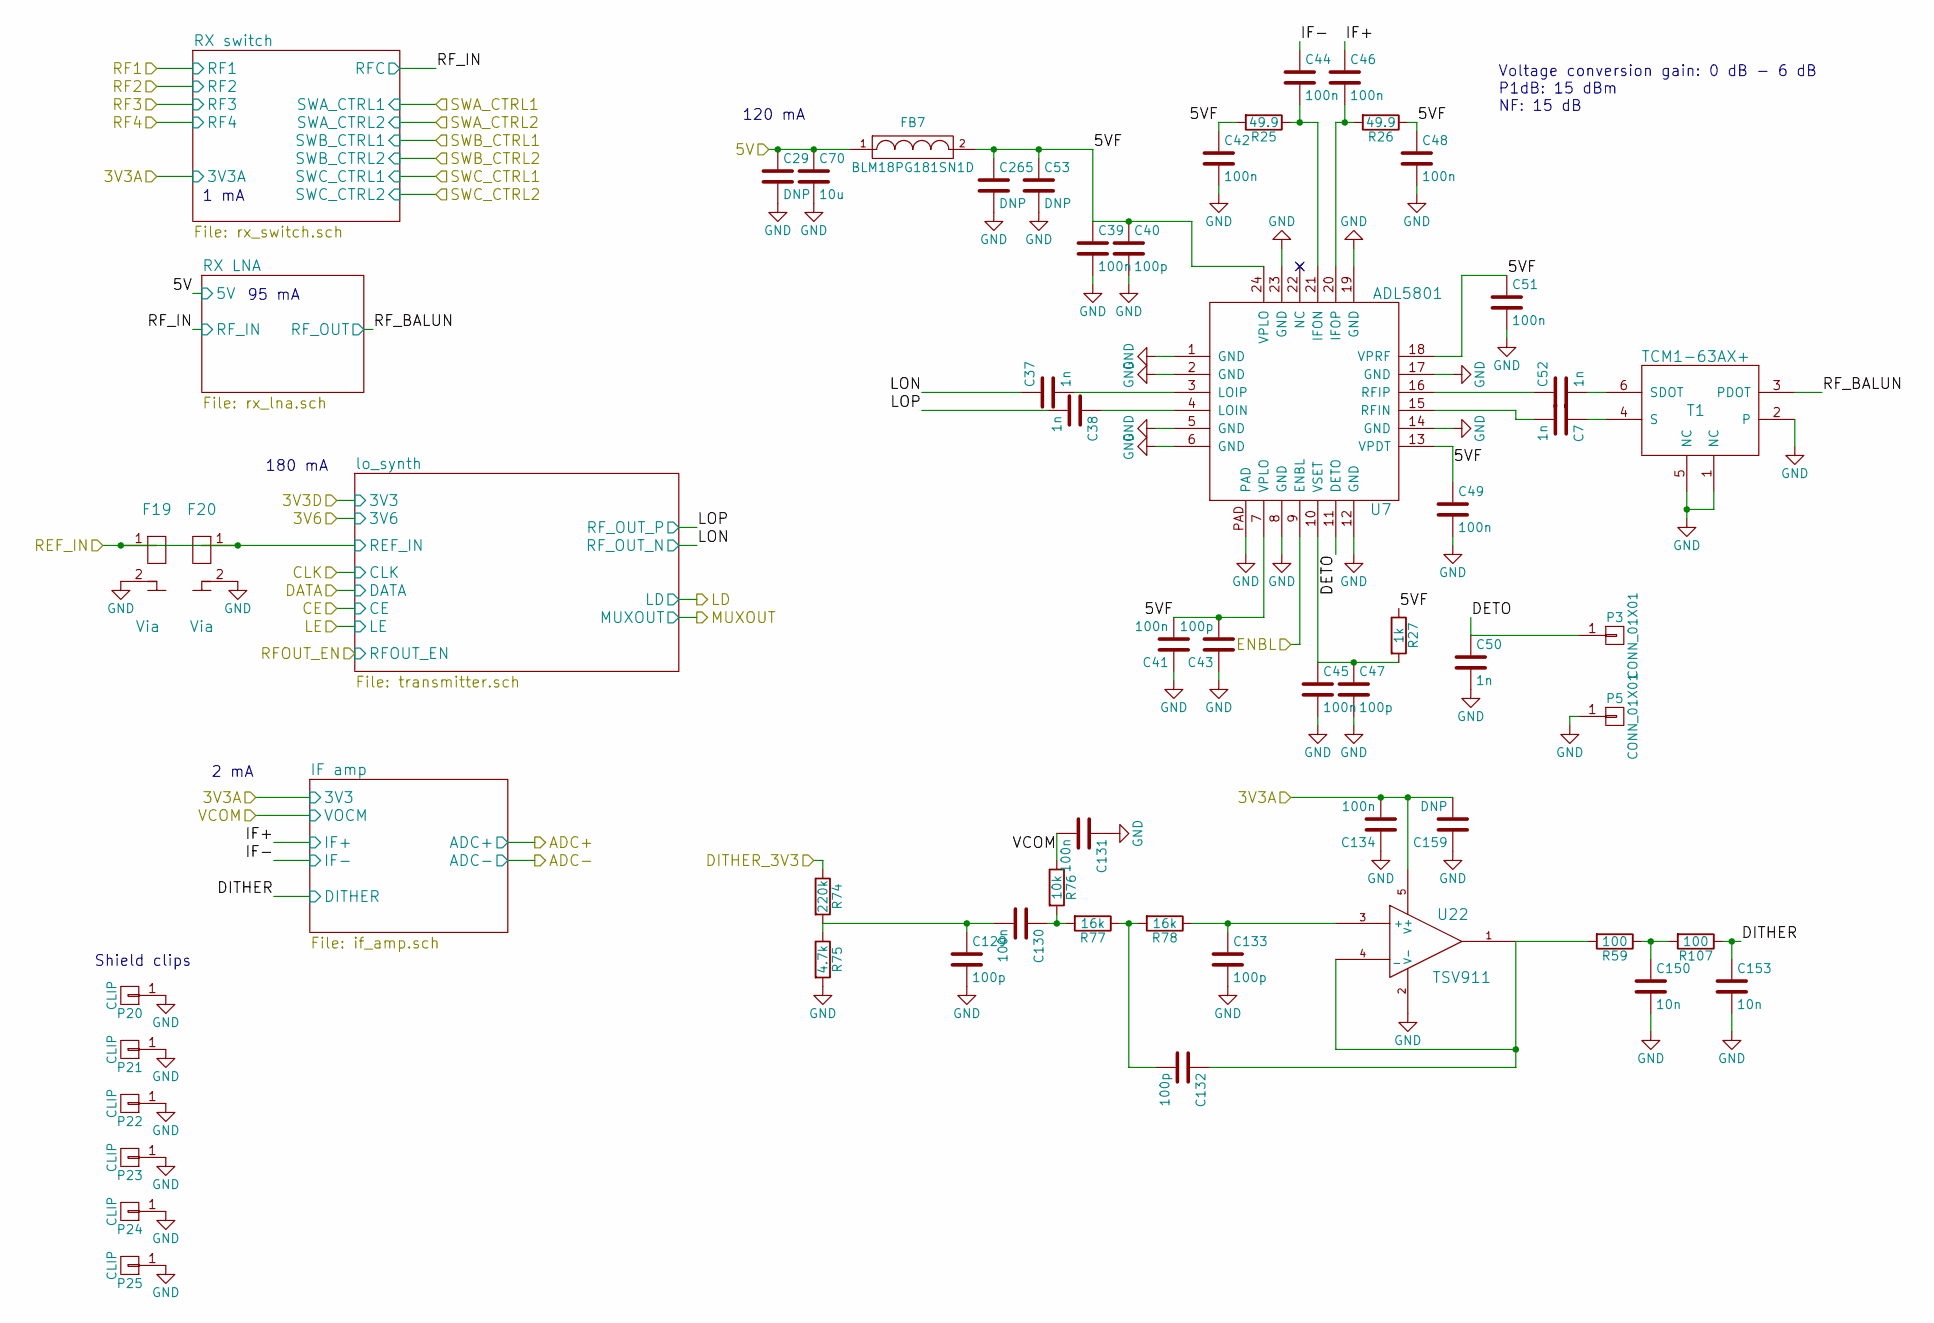
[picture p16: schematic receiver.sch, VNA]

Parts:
C7, C37, C38, C50, C52: 1n; C_0402b
C29: DNP; C_0603b
C39, C41, C42, C44, C45, C46, C48, C49, C51, C130, C131, C134: 100n; C_0402b
C40, C43, C47, C129, C132, C133: 100p; C_0402b
C53, C159, C265: DNP; C_0805b
C70: 10u; C_0805b
C150, C153: 10n; C_0402b
F19, F20: Via; RF_via
FB7: BLM18PG181SN1D; C_0603b
P3, P5: CONN_01X01; TP_1.00
P20, P21, P22, P23, P24, P25: CLIP; S2711-46R
R25, R26: 49.9; R_0402b
R27: 1k; R_0402b
R59, R107: 100; R_0402b
R74: 220k; R_0402b
R75: 4.7k; R_0402b
R76: 10k; R_0402b
R77, R78: 16k; R_0402b
T1: TCM1-63AX+
U7: ADL5801; VFQFN-24
U22: TSV911; SOT-23-5

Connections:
3V3A_RX: C134.2, C159.2, U22.5 (V+); also elsewhere on the board
/5V: C29.1, C70.1, FB7.1; also elsewhere on the board
/ADC_VCM: C131.2, R76.1; also elsewhere on the board
/CLK_LO: F19.1, F20.1; also elsewhere on the board
/DITHER: R74.1; also elsewhere on the board
/MIXER_ENABLE: U7.9 (ENBL); also elsewhere on the board
/receiver/5VF: C39.1, C40.1, C41.2, C42.1, C43.2, C48.1, C49.1, C51.1, C53.1, C265.1, FB7.2, R25.2, R26.1, R27.1, U7.7 (VPLO), U7.13 (VPDT), U7.18 (VPRF), U7.24 (VPLO)
/receiver/DETO: C50.1, P3.1, U7.11 (DETO)
/receiver/DITHER: C153.1, R107.1; also elsewhere on the board
/receiver/IF+: C46.1; also elsewhere on the board
/receiver/IF-: C44.1; also elsewhere on the board
/receiver/LON: C37.1; also elsewhere on the board
/receiver/LOP: C38.2; also elsewhere on the board
/receiver/RF_BALUN: T1.3 (PDOT); also elsewhere on the board
GND: C29.2, C39.2, C40.2, C41.1, C42.2, C43.1, C45.2, C47.2, C48.2, C49.2, C50.2, C51.2, C53.2, C70.2, C129.2, C131.1, C133.2, C134.1, C150.2, C153.2, C159.1, C265.2, F19.2, F20.2, P5.1, P20.1, P21.1, P22.1, P23.1, P24.1, P25.1, R75.2, T1.1 (NC), T1.2, T1.5 (NC), U7.1 (GND), U7.2 (GND), U7.5 (GND), U7.6 (GND), U7.8 (GND), U7.12 (GND), U7.14 (GND), U7.17 (GND), U7.19 (GND), U7.23 (GND), U7.PAD, U22.2 (V-); also elsewhere on the board
unnamed: C7.1, T1.4 (S)
unnamed: C7.2, U7.15 (RFIN)
unnamed: C37.2, U7.3 (LOIP)
unnamed: C38.1, U7.4 (LOIN)
unnamed: C44.2, R25.1, U7.21 (IFON)
unnamed: C45.1, C47.1, R27.2, U7.10 (VSET)
unnamed: C46.2, R26.2, U7.20 (IFOP)
unnamed: C52.1, U7.16 (RFIP)
unnamed: C52.2, T1.6 (SDOT)
unnamed: C129.1, C130.2, R74.2, R75.1
unnamed: C130.1, R76.2, R77.2
unnamed: C132.1, R59.2, U22.1, U22.4 (_)
unnamed: C132.2, R77.1, R78.2
unnamed: C133.1, R78.1, U22.3 (+)
unnamed: C150.1, R59.1, R107.2

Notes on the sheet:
Voltage conversion gain: 0 dB - 6 dB P1dB: 15 dBm NF: 15 dB
120 mA
180 mA
2 mA
Shield clips
1 mA
95 mA

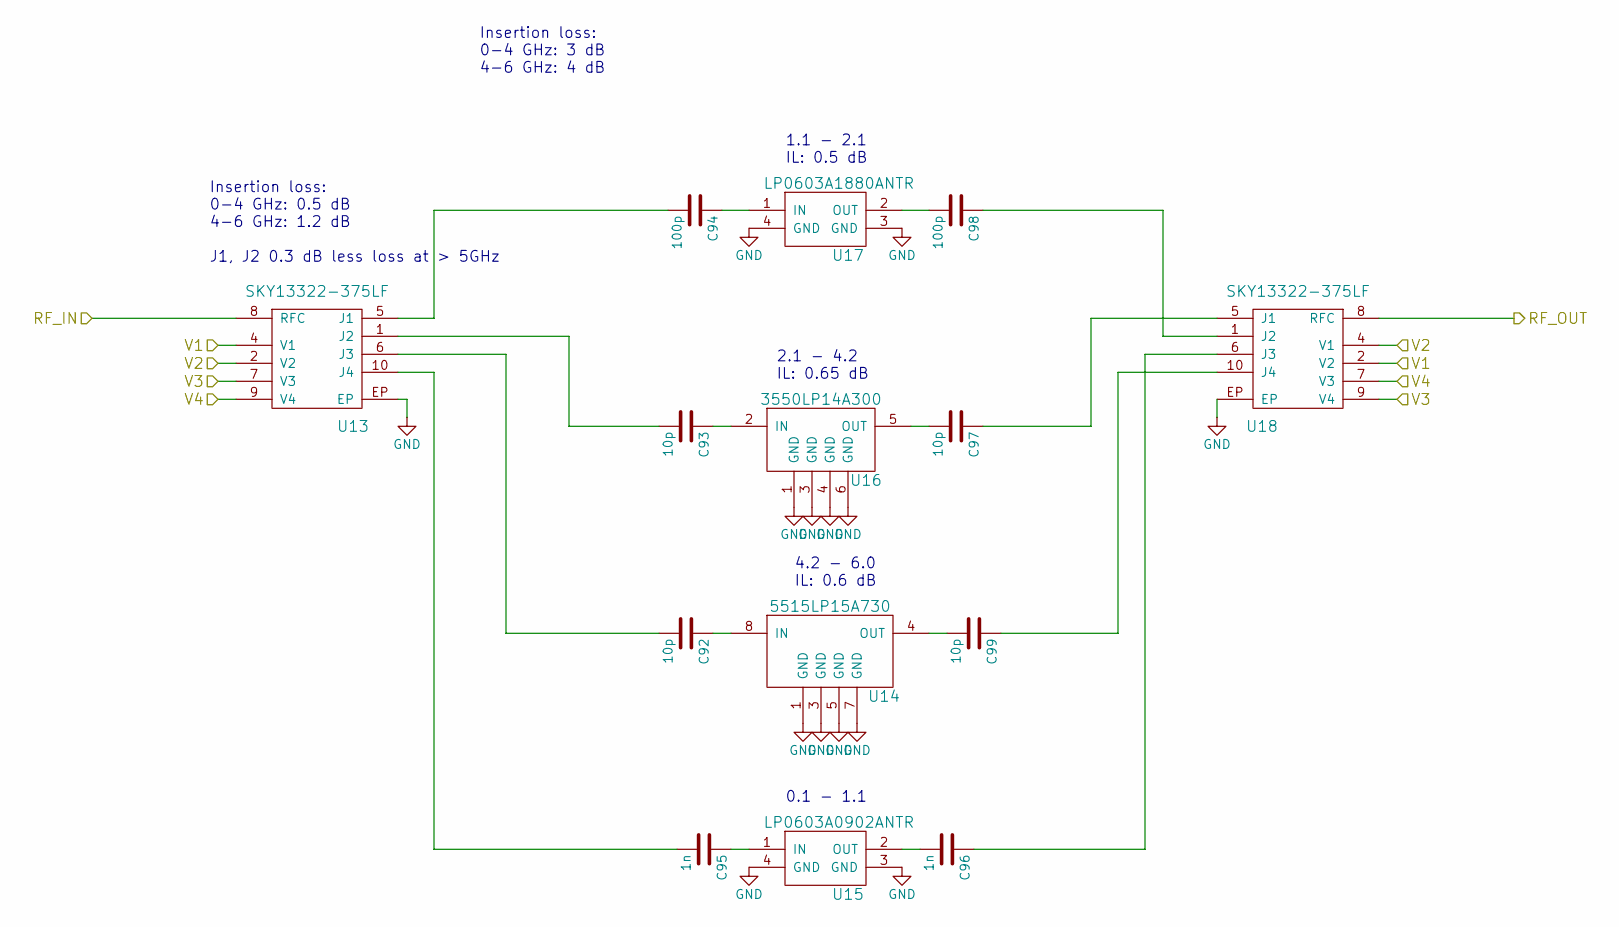
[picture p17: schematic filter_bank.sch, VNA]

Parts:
C92, C93, C97, C99: 10p; C_0402b
C94, C98: 100p; C_0402b
C95, C96: 1n; C_0402b
U13, U18: SKY13322-375LF; MLPD-10
U14: 5515LP15A730
U15: LP0603A0902ANTR; LP0603A0902
U16: 3550LP14A300
U17: LP0603A1880ANTR; LP0603A0902

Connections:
/FILTER_V1: U13.4 (V1), U18.2 (V2); also elsewhere on the board
/FILTER_V2: U13.2 (V2), U18.4 (V1); also elsewhere on the board
/FILTER_V3: U13.7 (V3), U18.9 (V4); also elsewhere on the board
/FILTER_V4: U13.9 (V4), U18.7 (V3); also elsewhere on the board
/filter_bank/RF_IN: U13.8 (RFC); also elsewhere on the board
/filter_bank/RF_OUT: U18.8 (RFC); also elsewhere on the board
GND: U13.EP, U14.1 (GND), U14.3 (GND), U14.5 (GND), U14.7 (GND), U15.3 (GND), U15.4 (GND), U16.1 (GND), U16.3 (GND), U16.4 (GND), U16.6 (GND), U17.3 (GND), U17.4 (GND), U18.EP; also elsewhere on the board
unnamed: C92.1, U14.8 (IN)
unnamed: C92.2, U13.6 (J3)
unnamed: C93.1, U16.2 (IN)
unnamed: C93.2, U13.1 (J2)
unnamed: C94.1, U17.1 (IN)
unnamed: C94.2, U13.5 (J1)
unnamed: C95.1, U15.1 (IN)
unnamed: C95.2, U13.10 (J4)
unnamed: C96.1, U18.6 (J3)
unnamed: C96.2, U15.2 (OUT)
unnamed: C97.1, U18.5 (J1)
unnamed: C97.2, U16.5 (OUT)
unnamed: C98.1, U18.1 (J2)
unnamed: C98.2, U17.2 (OUT)
unnamed: C99.1, U18.10 (J4)
unnamed: C99.2, U14.4 (OUT)

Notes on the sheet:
Insertion loss: 0-4 GHz: 0.5 dB 4-6 GHz: 1.2 dB J1, J2 0.3 dB less loss at > 5GHz
Insertion loss: 0-4 GHz: 3 dB 4-6 GHz: 4 dB
4.2 - 6.0 IL: 0.6 dB
2.1 - 4.2 IL: 0.65 dB
1.1 - 2.1 IL: 0.5 dB
0.1 - 1.1

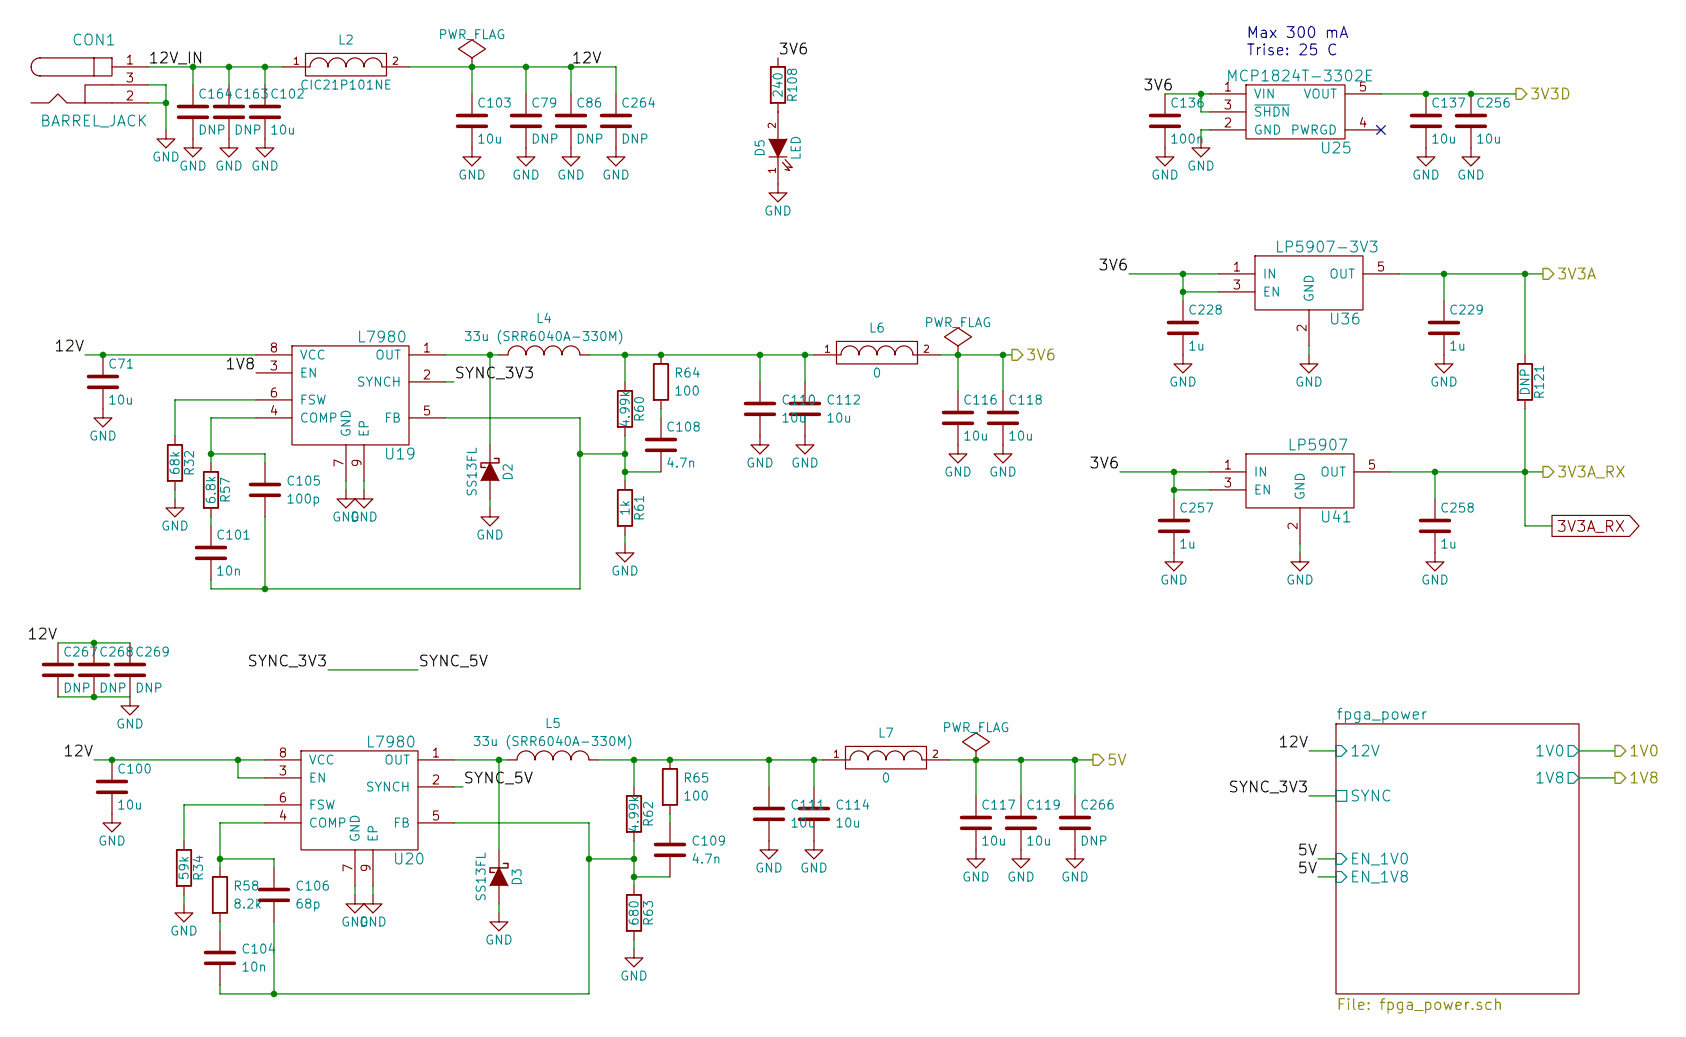
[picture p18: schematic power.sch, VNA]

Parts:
C71, C100, C102, C103, C110, C111, C112, C114, C116, C117, C118, C119, C137, C256: 10u; C_0805b
C79, C86, C163, C164, C264, C266, C267, C268, C269: DNP; C_0805b
C101, C104: 10n; C_0402b
C105: 100p; C_0402b
C106: 68p; C_0402b
C108, C109: 4.7n; C_0402b
C136: 100n; C_0402b
C228, C229, C257, C258: 1u; C_0603b
CON1: BARREL_JACK; EJ508A
D2, D3: SS13FL; SOD-123F
D5: LED; LED_0603
L2: CIC21P101NE; C_0805b
L4, L5: 33u (SRR6040A-330M); SRR6040A
L6, L7: 0; C_0805b
R32: 68k; R_0402b
R34: 59k; R_0402b
R57: 6.8k; R_0402b
R58: 8.2k; R_0402b
R60, R62: 4.99k; R_0402b
R61: 1k; R_0402b
R63: 680; R_0402b
R64, R65: 100; R_0402b
R108: 240; R_0402b
R121: DNP; R_0402b
U19, U20: L7980; DFN-8-1EP_3x3mm_Pitch0.5mm
U25: MCP1824T-3302E; SOT-23-5
U36: LP5907-3V3; SOT-23-5
U41: LP5907; SOT-23-5

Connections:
3V3A_RX: C258.1, R121.2, U41.5 (OUT); also elsewhere on the board
/1V8: U19.3 (EN); also elsewhere on the board
/3V3A: C229.1, R121.1, U36.5 (OUT); also elsewhere on the board
/3V3D: C137.1, C256.1, U25.5 (VOUT); also elsewhere on the board
/3V6: C116.1, C118.1, C136.1, C228.1, C257.1, L6.2, R108.1, U25.1 (VIN), U25.3 (~SHDN), U36.1 (IN), U36.3 (EN), U41.1 (IN), U41.3 (EN); also elsewhere on the board
/5V: C117.1, C119.1, C266.1, L7.2; also elsewhere on the board
/power/12V: C71.1, C79.1, C86.1, C100.1, C103.1, C264.1, C267.1, C268.1, C269.1, L2.2, U19.8 (VCC), U20.3 (EN), U20.8 (VCC); also elsewhere on the board
/power/12V_IN: C102.1, C163.1, C164.1, CON1.1, L2.1
/power/SYNC_3V3: U19.2 (SYNCH), U20.2 (SYNCH); also elsewhere on the board
GND: C71.2, C79.2, C86.2, C100.2, C102.2, C103.2, C110.2, C111.2, C112.2, C114.2, C116.2, C117.2, C118.2, C119.2, C136.2, C137.2, C163.2, C164.2, C228.2, C229.2, C256.2, C257.2, C258.2, C264.2, C266.2, C267.2, C268.2, C269.2, CON1.2, CON1.3, D2.2 (A), D3.2 (A), D5.1 (K), R32.2, R34.2, R61.2, R63.2, U19.7 (GND), U19.9 (EP), U20.7 (GND), U20.9 (EP), U25.2 (GND), U36.2 (GND), U41.2 (GND); also elsewhere on the board
unnamed: C101.1, R57.2
unnamed: C101.2, C105.2, C108.2, R60.2, R61.1, U19.5 (FB)
unnamed: C104.1, R58.2
unnamed: C104.2, C106.2, C109.2, R62.2, R63.1, U20.5 (FB)
unnamed: C105.1, R57.1, U19.4 (COMP)
unnamed: C106.1, R58.1, U20.4 (COMP)
unnamed: C108.1, R64.2
unnamed: C109.1, R65.2
unnamed: C110.1, C112.1, L4.2, L6.1, R60.1, R64.1
unnamed: C111.1, C114.1, L5.2, L7.1, R62.1, R65.1
unnamed: D2.1 (K), L4.1, U19.1 (OUT)
unnamed: D3.1 (K), L5.1, U20.1 (OUT)
unnamed: D5.2 (A), R108.2
unnamed: R32.1, U19.6 (FSW)
unnamed: R34.1, U20.6 (FSW)

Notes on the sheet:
Max 300 mA Trise: 25 C

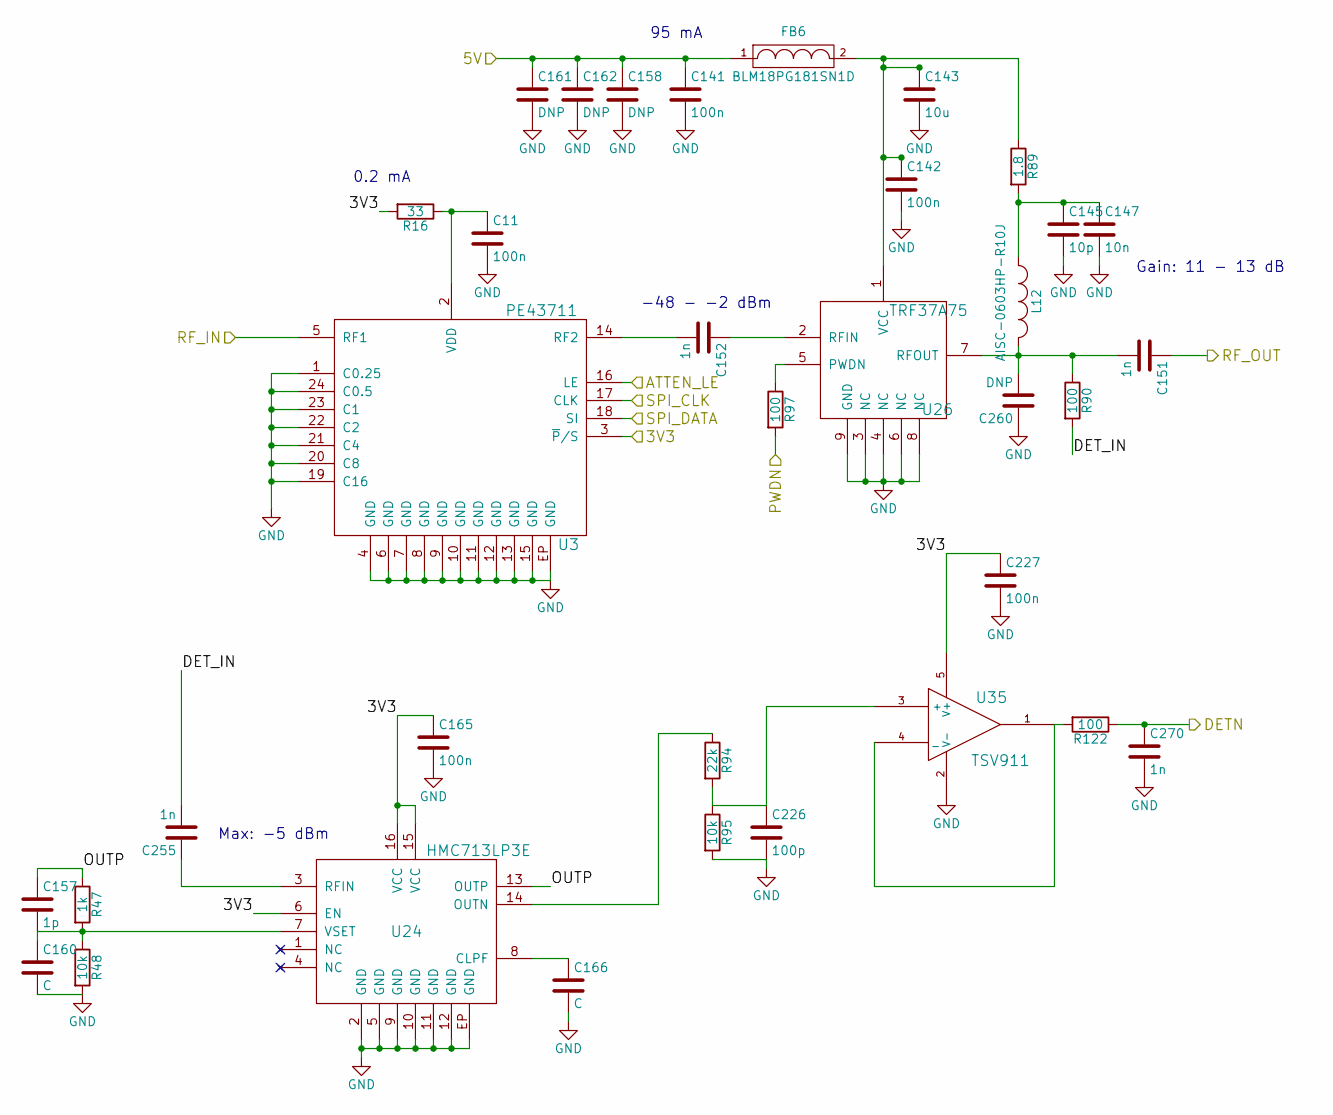
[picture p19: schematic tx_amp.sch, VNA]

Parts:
C11, C141, C142, C165, C227: 100n; C_0402b
C143: 10u; C_0805b
C145: 10p; C_0402b
C147: 10n; C_0402b
C151, C152, C255, C270: 1n; C_0402b
C157: 1p; C_0402b
C158: DNP; C_0805b
C160, C166: C; C_0402b
C161, C162, C260: DNP; C_0402b
C226: 100p; C_0402b
FB6: BLM18PG181SN1D; C_0603b
L12: AISC-0603HP-R10J; C_0603b
R16: 33; R_0402b
R47: 1k; R_0402b
R48, R95: 10k; R_0402b
R89: 1.8; R_0603b
R90, R97, R122: 100; R_0402b
R94: 22k; R_0402b
U3: PE43711; VQFN-24
U24: HMC713LP3E; VFQFN-16
U26: TRF37A75; DFN-8-1EP_2x2mm_Pitch0.5mm
U35: TSV911; SOT-23-5

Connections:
/3V3A: C165.1, C227.1, R16.2, U3.3 (~P~/S), U24.6 (EN), U24.15 (VCC), U24.16 (VCC), U35.5 (V+); also elsewhere on the board
/5V: C141.1, C158.1, C161.1, C162.1, FB6.1; also elsewhere on the board
/ATTEN_LE: U3.16 (LE); also elsewhere on the board
/ATTEN_SPI_DATA: U3.18 (SI); also elsewhere on the board
/PDET: C270.1, R122.1; also elsewhere on the board
/PWDN: R97.2; also elsewhere on the board
/SPI_CLK: U3.17 (CLK); also elsewhere on the board
/port switch/RFC: C151.1; also elsewhere on the board
/tx_amp/DET_IN: C255.2, R90.2
/tx_amp/OUTP: C157.1, R47.1, U24.13 (OUTP)
/tx_amp/RF_IN: U3.5 (RF1); also elsewhere on the board
GND: C11.2, C141.2, C142.2, C143.2, C145.2, C147.2, C158.2, C160.2, C161.2, C162.2, C165.2, C166.2, C226.2, C227.2, C260.1, C270.2, R48.2, R95.2, U3.1 (C0.25), U3.4 (GND), U3.6 (GND), U3.7 (GND), U3.8 (GND), U3.9 (GND), U3.10 (GND), U3.11 (GND), U3.12 (GND), U3.13 (GND), U3.15 (GND), U3.19 (C16), U3.20 (C8), U3.21 (C4), U3.22 (C2), U3.23 (C1), U3.24 (C0.5), U3.EP (GND), U24.2 (GND), U24.5 (GND), U24.9 (GND), U24.10 (GND), U24.11 (GND), U24.12 (GND), U24.EP (GND), U26.3 (NC), U26.4 (NC), U26.6 (NC), U26.8 (NC), U26.9 (GND), U35.2 (V-); also elsewhere on the board
unnamed: C11.1, R16.1, U3.2 (VDD)
unnamed: C142.1, C143.1, FB6.2, R89.1, U26.1 (VCC)
unnamed: C145.1, C147.1, L12.1, R89.2
unnamed: C151.2, C260.2, L12.2, R90.1, U26.7 (RFOUT)
unnamed: C152.1, U26.2 (RFIN)
unnamed: C152.2, U3.14 (RF2)
unnamed: C157.2, C160.1, R47.2, R48.1, U24.7 (VSET)
unnamed: C166.1, U24.8 (CLPF)
unnamed: C226.1, R94.2, R95.1, U35.3 (+)
unnamed: C255.1, U24.3 (RFIN)
unnamed: R94.1, U24.14 (OUTN)
unnamed: R97.1, U26.5 (PWDN)
unnamed: R122.2, U35.1, U35.4 (_)

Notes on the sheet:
-48 - -2 dBm
Gain: 11 - 13 dB
95 mA
0.2 mA
Max: -5 dBm

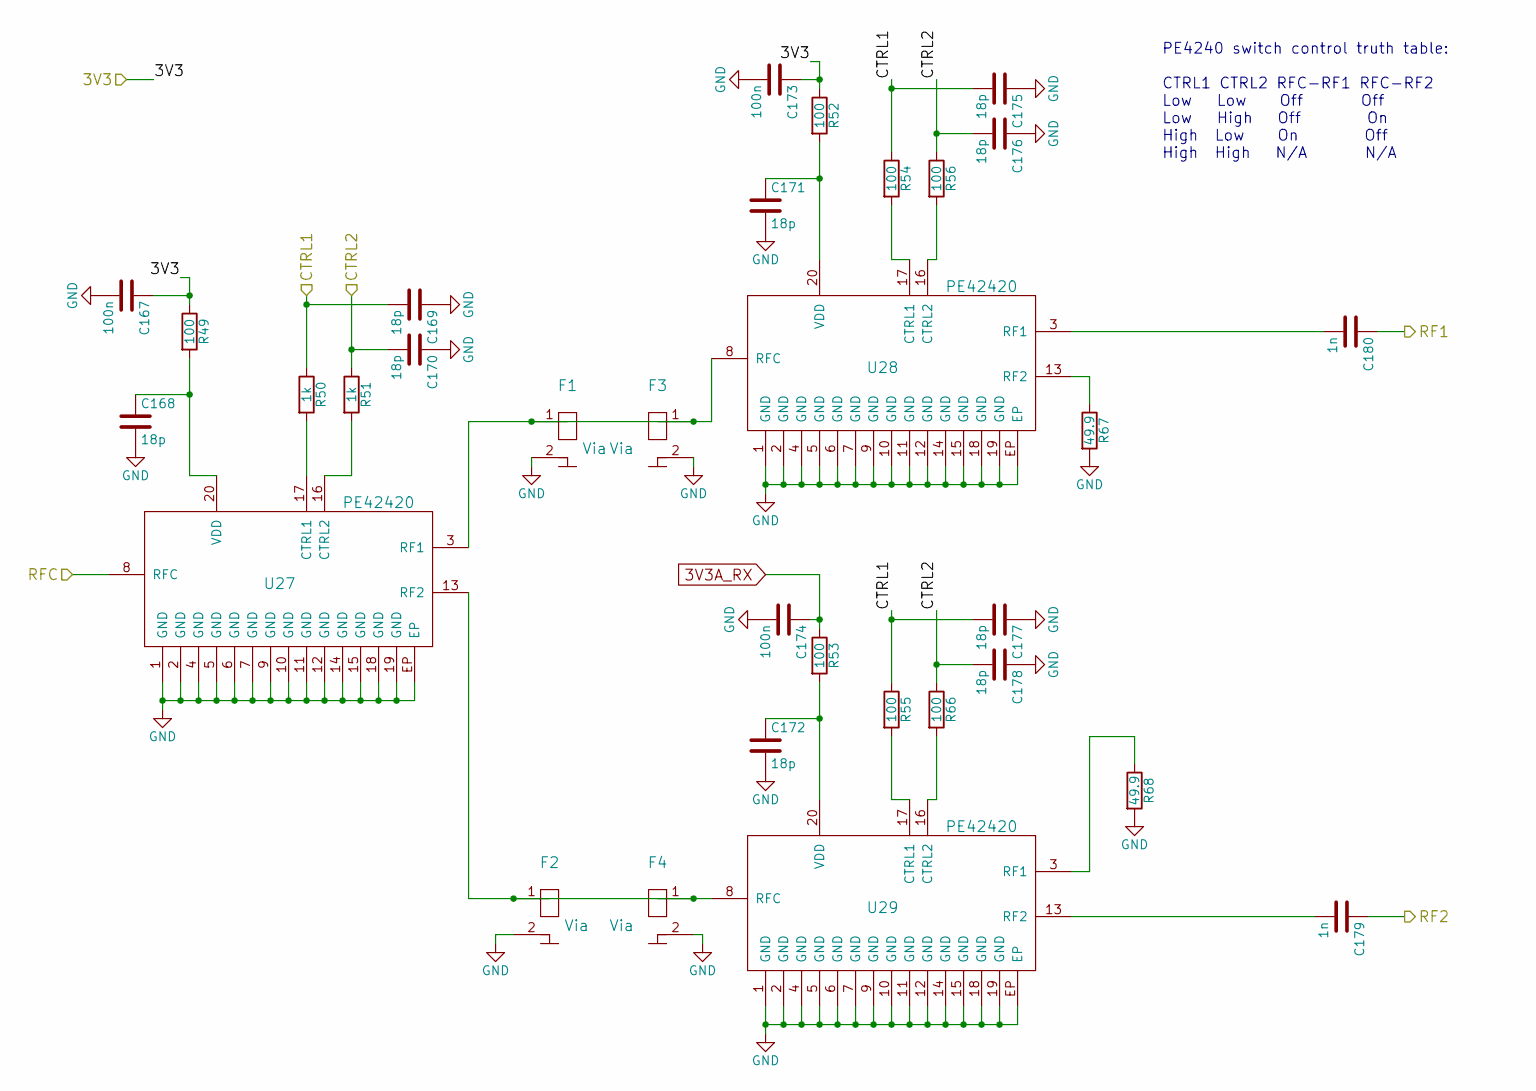
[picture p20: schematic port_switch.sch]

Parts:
C167, C173, C174: 100n; C_0402b
C168, C169, C170, C171, C172, C175, C176, C177, C178: 18p; C_0402b
C179, C180: 1n; C_0402b
F1, F2, F3, F4: Via; RF_via
R49, R52, R53, R54, R55, R56, R66: 100; R_0402b
R50, R51: 1k; R_0402b
R67, R68: 49.9; R_0402b
U27, U28, U29: PE42420; TFLGA-20

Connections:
3V3A_RX: C174.1, R53.1; also elsewhere on the board
/3V3A: C167.1, C173.1, R49.1, R52.1; also elsewhere on the board
/PORT1: C180.1; also elsewhere on the board
/PORT2: C179.1; also elsewhere on the board
/PORT_SW0: C169.2, C175.2, C177.2, R50.1, R54.1, R55.1; also elsewhere on the board
/PORT_SW1: C170.2, C176.2, C178.2, R51.1, R56.1, R66.1; also elsewhere on the board
/port switch/RFC: U27.8 (RFC); also elsewhere on the board
GND: C167.2, C168.2, C169.1, C170.1, C171.2, C172.2, C173.2, C174.2, C175.1, C176.1, C177.1, C178.1, F1.2, F2.2, F3.2, F4.2, R67.2, R68.2, U27.1 (GND), U27.2 (GND), U27.4 (GND), U27.5 (GND), U27.6 (GND), U27.7 (GND), U27.9 (GND), U27.10 (GND), U27.11 (GND), U27.12 (GND), U27.14 (GND), U27.15 (GND), U27.18 (GND), U27.19 (GND), U27.EP, U28.1 (GND), U28.2 (GND), U28.4 (GND), U28.5 (GND), U28.6 (GND), U28.7 (GND), U28.9 (GND), U28.10 (GND), U28.11 (GND), U28.12 (GND), U28.14 (GND), U28.15 (GND), U28.18 (GND), U28.19 (GND), U28.EP, U29.1 (GND), U29.2 (GND), U29.4 (GND), U29.5 (GND), U29.6 (GND), U29.7 (GND), U29.9 (GND), U29.10 (GND), U29.11 (GND), U29.12 (GND), U29.14 (GND), U29.15 (GND), U29.18 (GND), U29.19 (GND), U29.EP; also elsewhere on the board
unnamed: C168.1, R49.2, U27.20 (VDD)
unnamed: C171.1, R52.2, U28.20 (VDD)
unnamed: C172.1, R53.2, U29.20 (VDD)
unnamed: C179.2, U29.13 (RF2)
unnamed: C180.2, U28.3 (RF1)
unnamed: F1.1, F3.1, U27.3 (RF1), U28.8 (RFC)
unnamed: F2.1, F4.1, U27.13 (RF2), U29.8 (RFC)
unnamed: R50.2, U27.17 (CTRL1)
unnamed: R51.2, U27.16 (CTRL2)
unnamed: R54.2, U28.17 (CTRL1)
unnamed: R55.2, U29.17 (CTRL1)
unnamed: R56.2, U28.16 (CTRL2)
unnamed: R66.2, U29.16 (CTRL2)
unnamed: R67.1, U28.13 (RF2)
unnamed: R68.1, U29.3 (RF1)

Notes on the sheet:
PE4240 switch control truth table: CTRL1 CTRL2 RFC-RF1 RFC-RF2 Low Low Off Off Low High Off On High Low On Off High High N/A N/A

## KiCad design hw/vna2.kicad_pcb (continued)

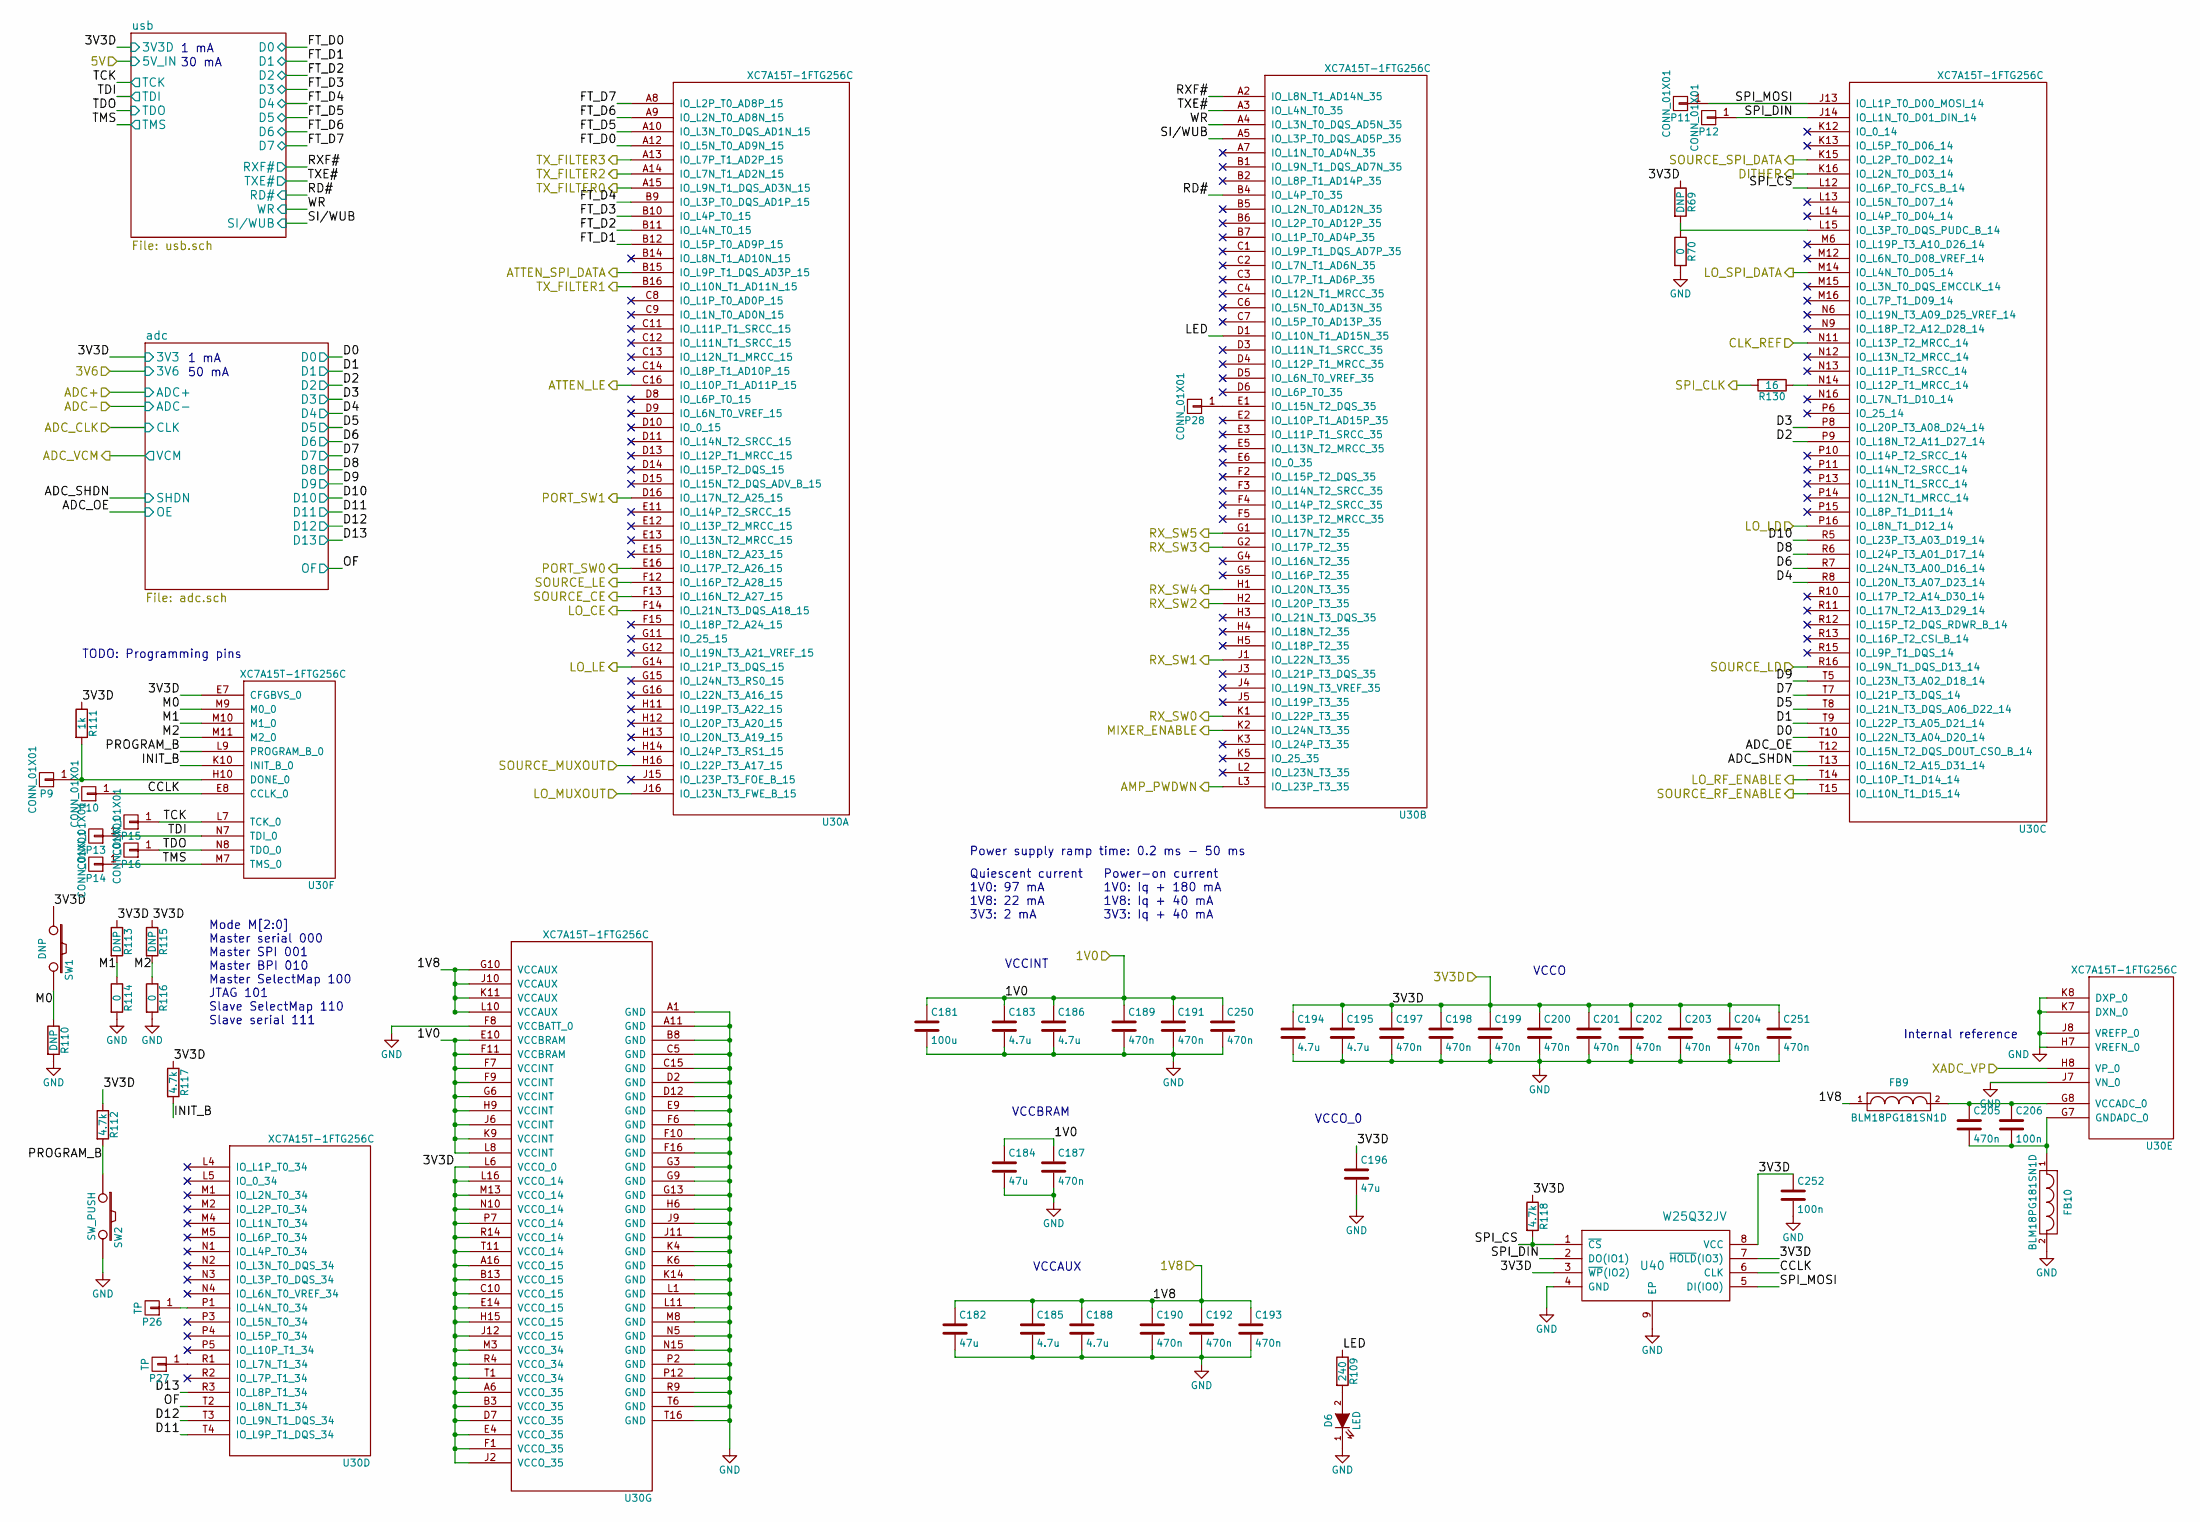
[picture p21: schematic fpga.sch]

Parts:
C181: 100u; C_1210
C182, C184, C196: 47u; C_1206
C183, C185, C186, C188, C194, C195: 4.7u; C_0805b
C187, C189, C190, C191, C192, C193, C197, C198, C199, C200, C201, C202, C203, C204, C205, C250, C251: 470n; C_0402b
C206, C252: 100n; C_0402b
D6: LED; LED_0603
FB9, FB10: BLM18PG181SN1D; C_0603b
P9, P10, P11, P12, P13, P14, P15, P16, P28: CONN_01X01; TP_1.00
P26, P27: TP; TP_1.00
R69, R110, R113, R115: DNP; R_0402b
R70, R114, R116: 0; R_0402b
R109: 240; R_0402b
R111: 1k; R_0402b
R112, R117, R118: 4.7k; R_0402b
R130: 16; R_0402b
SW1: DNP; EVP-AWBA2A
SW2: SW_PUSH; EVP-AWBA2A
U30: XC7A15T-1FTG256C; FTG256
U40: W25Q32JV; DFN-S-8-1EP_6x5mm_Pitch1.27mm

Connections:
/1V0: C181.1, C183.1, C184.1, C186.1, C187.1, C189.1, C191.1, C250.1, U30.E10 (VCCBRAM), U30.F7 (VCCINT), U30.F9 (VCCINT), U30.F11 (VCCBRAM), U30.G6 (VCCINT), U30.H9 (VCCINT), U30.J6 (VCCINT), U30.K9 (VCCINT), U30.L8 (VCCINT); also elsewhere on the board
/1V8: C182.1, C185.1, C188.1, C190.1, C192.1, C193.1, FB9.1, U30.G10 (VCCAUX), U30.J10 (VCCAUX), U30.K11 (VCCAUX), U30.L10 (VCCAUX); also elsewhere on the board
/3V3D: C194.1, C195.1, C196.1, C197.1, C198.1, C199.1, C200.1, C201.1, C202.1, C203.1, C204.1, C251.1, C252.1, R69.1, R111.1, R112.1, R113.1, R115.1, R117.1, R118.1, SW1.1, U30.A6 (VCCO_35), U30.A16 (VCCO_15), U30.B3 (VCCO_35), U30.B13 (VCCO_15), U30.C10 (VCCO_15), U30.D7 (VCCO_35), U30.E4 (VCCO_35), U30.E7 (CFGBVS_0), U30.E14 (VCCO_15), U30.F1 (VCCO_35), U30.H15 (VCCO_15), U30.J2 (VCCO_35), U30.J12 (VCCO_15), U30.L6 (VCCO_0), U30.L16 (VCCO_14), U30.M3 (VCCO_34), U30.M13 (VCCO_14), U30.N10 (VCCO_14), U30.P7 (VCCO_14), U30.R4 (VCCO_34), U30.R14 (VCCO_14), U30.T1 (VCCO_34), U30.T11 (VCCO_14), U40.3 (~WP~(IO2)), U40.7 (~HOLD~(IO3)), U40.8 (VCC); also elsewhere on the board
/ATTEN_LE: U30.C16 (IO_L10P_T1_AD11P_15); also elsewhere on the board
/ATTEN_SPI_DATA: U30.B15 (IO_L9P_T1_DQS_AD3P_15); also elsewhere on the board
/CLK_FPGA: U30.N11 (IO_L13P_T2_MRCC_14); also elsewhere on the board
/DITHER: U30.K16 (IO_L2N_T0_D03_14); also elsewhere on the board
/FILTER_V1: U30.A15 (IO_L9N_T1_DQS_AD3N_15); also elsewhere on the board
/FILTER_V2: U30.B16 (IO_L10N_T1_AD11N_15); also elsewhere on the board
/FILTER_V3: U30.A14 (IO_L7N_T1_AD2N_15); also elsewhere on the board
/FILTER_V4: U30.A13 (IO_L7P_T1_AD2P_15); also elsewhere on the board
/LO_CE: U30.F14 (IO_L21N_T3_DQS_A18_15); also elsewhere on the board
/LO_LD: U30.P16 (IO_L8N_T1_D12_14); also elsewhere on the board
/LO_LE: U30.G14 (IO_L21P_T3_DQS_15); also elsewhere on the board
/LO_MUXOUT: U30.J16 (IO_L23N_T3_FWE_B_15); also elsewhere on the board
/LO_RF_ENABLE: U30.T14 (IO_L10P_T1_D14_14); also elsewhere on the board
/LO_SPI_DATA: U30.M14 (IO_L4N_T0_D05_14); also elsewhere on the board
/MIXER_ENABLE: U30.K2 (IO_L24N_T3_35); also elsewhere on the board
/PDET: U30.H8 (VP_0); also elsewhere on the board
/PORT_SW0: U30.E16 (IO_L17P_T2_A26_15); also elsewhere on the board
/PORT_SW1: U30.D16 (IO_L17N_T2_A25_15); also elsewhere on the board
/PWDN: U30.L3 (IO_L23P_T3_35); also elsewhere on the board
/RX_SW0: U30.K1 (IO_L22P_T3_35); also elsewhere on the board
/RX_SW1: U30.J1 (IO_L22N_T3_35); also elsewhere on the board
/RX_SW2: U30.H2 (IO_L20P_T3_35); also elsewhere on the board
/RX_SW3: U30.G2 (IO_L17P_T2_35); also elsewhere on the board
/RX_SW4: U30.H1 (IO_L20N_T3_35); also elsewhere on the board
/RX_SW5: U30.G1 (IO_L17N_T2_35); also elsewhere on the board
/SOURCE_CE: U30.F13 (IO_L16N_T2_A27_15); also elsewhere on the board
/SOURCE_LD: U30.R16 (IO_L9N_T1_DQS_D13_14); also elsewhere on the board
/SOURCE_LE: U30.F12 (IO_L16P_T2_A28_15); also elsewhere on the board
/SOURCE_MUXOUT: U30.H16 (IO_L22P_T3_A17_15); also elsewhere on the board
/SOURCE_RF_ENABLE: U30.T15 (IO_L10N_T1_D15_14); also elsewhere on the board
/SOURCE_SPI_DATA: U30.K15 (IO_L2P_T0_D02_14); also elsewhere on the board
/SPI_CLK: R130.2; also elsewhere on the board
/fpga/ADC_OE: U30.T12 (IO_L15N_T2_DQS_DOUT_CSO_B_14); also elsewhere on the board
/fpga/ADC_SHDN: U30.T13 (IO_L16N_T2_A15_D31_14); also elsewhere on the board
/fpga/CCLK: P10.1, U30.E8 (CCLK_0), U40.6 (CLK)
/fpga/D0: U30.T10 (IO_L22N_T3_A04_D20_14); also elsewhere on the board
/fpga/D1: U30.T9 (IO_L22P_T3_A05_D21_14); also elsewhere on the board
/fpga/D2: U30.P9 (IO_L18N_T2_A11_D27_14); also elsewhere on the board
/fpga/D3: U30.P8 (IO_L20P_T3_A08_D24_14); also elsewhere on the board
/fpga/D4: U30.R8 (IO_L20N_T3_A07_D23_14); also elsewhere on the board
/fpga/D5: U30.T8 (IO_L21N_T3_DQS_A06_D22_14); also elsewhere on the board
/fpga/D6: U30.R7 (IO_L24N_T3_A00_D16_14); also elsewhere on the board
/fpga/D7: U30.T7 (IO_L21P_T3_DQS_14); also elsewhere on the board
/fpga/D8: U30.R6 (IO_L24P_T3_A01_D17_14); also elsewhere on the board
/fpga/D9: U30.T5 (IO_L23N_T3_A02_D18_14); also elsewhere on the board
/fpga/D10: U30.R5 (IO_L23P_T3_A03_D19_14); also elsewhere on the board
/fpga/D11: U30.T4 (IO_L9P_T1_DQS_34); also elsewhere on the board
/fpga/D12: U30.T3 (IO_L9N_T1_DQS_34); also elsewhere on the board
/fpga/D13: U30.R3 (IO_L8P_T1_34); also elsewhere on the board
/fpga/FT_D0: U30.A12 (IO_L5N_T0_AD9N_15); also elsewhere on the board
/fpga/FT_D1: U30.B12 (IO_L5P_T0_AD9P_15); also elsewhere on the board
/fpga/FT_D2: U30.B11 (IO_L4N_T0_15); also elsewhere on the board
/fpga/FT_D3: U30.B10 (IO_L4P_T0_15); also elsewhere on the board
/fpga/FT_D4: U30.B9 (IO_L3P_T0_DQS_AD1P_15); also elsewhere on the board
/fpga/FT_D5: U30.A10 (IO_L3N_T0_DQS_AD1N_15); also elsewhere on the board
/fpga/FT_D6: U30.A9 (IO_L2N_T0_AD8N_15); also elsewhere on the board
/fpga/FT_D7: U30.A8 (IO_L2P_T0_AD8P_15); also elsewhere on the board
/fpga/INIT_B: R117.2, U30.K10 (INIT_B_0)
/fpga/LED: R109.1, U30.D1 (IO_L10N_T1_AD15N_35)
/fpga/M0: R110.1, SW1.2, U30.M9 (M0_0)
/fpga/M1: R113.2, R114.1, U30.M10 (M1_0)
/fpga/M2: R115.2, R116.1, U30.M11 (M2_0)
/fpga/OF: U30.T2 (IO_L8N_T1_34); also elsewhere on the board
/fpga/PROGRAM_B: R112.2, SW2.1, U30.L9 (PROGRAM_B_0)
/fpga/RD#: U30.B4 (IO_L4P_T0_35); also elsewhere on the board
/fpga/RXF#: U30.A2 (IO_L8N_T1_AD14N_35); also elsewhere on the board
/fpga/SI/WUB: U30.A5 (IO_L3P_T0_DQS_AD5P_35); also elsewhere on the board
/fpga/SPI_CS: R118.2, U30.L12 (IO_L6P_T0_FCS_B_14), U40.1 (~CS)
/fpga/SPI_DIN: P12.1, U30.J14 (IO_L1N_T0_D01_DIN_14), U40.2 (DO(IO1))
/fpga/SPI_MOSI: P11.1, U30.J13 (IO_L1P_T0_D00_MOSI_14), U40.5 (DI(IO0))
/fpga/TCK: P15.1, U30.L7 (TCK_0); also elsewhere on the board
/fpga/TDI: P13.1, U30.N7 (TDI_0); also elsewhere on the board
/fpga/TDO: P16.1, U30.N8 (TDO_0); also elsewhere on the board
/fpga/TMS: P14.1, U30.M7 (TMS_0); also elsewhere on the board
/fpga/TXE#: U30.A3 (IO_L4N_T0_35); also elsewhere on the board
/fpga/WR: U30.A4 (IO_L3N_T0_DQS_AD5N_35); also elsewhere on the board
GND: C181.2, C182.2, C183.2, C184.2, C185.2, C186.2, C187.2, C188.2, C189.2, C190.2, C191.2, C192.2, C193.2, C194.2, C195.2, C196.2, C197.2, C198.2, C199.2, C200.2, C201.2, C202.2, C203.2, C204.2, C250.2, C251.2, C252.2, D6.1 (K), FB10.2, R70.2, R110.2, R114.2, R116.2, SW2.2, U30.A1 (GND), U30.A11 (GND), U30.B8 (GND), U30.C5 (GND), U30.C15 (GND), U30.D2 (GND), U30.D12 (GND), U30.E9 (GND), U30.F6 (GND), U30.F8 (VCCBATT_0), U30.F10 (GND), U30.F16 (GND), U30.G3 (GND), U30.G9 (GND), U30.G13 (GND), U30.H6 (GND), U30.H7 (VREFN_0), U30.J7 (VN_0), U30.J8 (VREFP_0), U30.J9 (GND), U30.J11 (GND), U30.K4 (GND), U30.K6 (GND), U30.K7 (DXN_0), U30.K8 (DXP_0), U30.K14 (GND), U30.L1 (GND), U30.L11 (GND), U30.M8 (GND), U30.N5 (GND), U30.N15 (GND), U30.P2 (GND), U30.P12 (GND), U30.R9 (GND), U30.T6 (GND), U30.T16 (GND), U40.4 (GND), U40.9 (EP); also elsewhere on the board
unnamed: C205.1, C206.1, FB9.2, U30.G8 (VCCADC_0)
unnamed: C205.2, C206.2, FB10.1, U30.G7 (GNDADC_0)
unnamed: D6.2 (A), R109.2
unnamed: P9.1, R111.2, U30.H10 (DONE_0)
unnamed: P26.1, U30.P1 (IO_L4N_T0_34)
unnamed: P27.1, U30.R1 (IO_L7N_T1_34)
unnamed: P28.1, U30.E1 (IO_L15N_T2_DQS_35)
unnamed: R69.2, R70.1, U30.L15 (IO_L3P_T0_DQS_PUDC_B_14)
unnamed: R130.1, U30.N14 (IO_L12P_T1_MRCC_14)

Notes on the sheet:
VCCINT
VCCBRAM
VCCAUX
VCCO_0
VCCO
Internal reference
Quiescent current 1V0: 97 mA 1V8: 22 mA 3V3: 2 mA
Power-on current 1V0: Iq + 180 mA 1V8: Iq + 40 mA 3V3: Iq + 40 mA
Power supply ramp time: 0.2 ms - 50 ms
50 mA
TODO: Programming pins
Mode M[2:0] Master serial 000 Master SPI 001 Master BPI 010 Master SelectMap 100 JTAG 101 Slave SelectMap 110 Slave serial 111
30 mA
1 mA

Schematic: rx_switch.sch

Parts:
C8, C9, C12, C28: 1n; C_0402b
C35, C36, C54, C77, C81, C82, C83, C84, C85: 18p; C_0402b
C78, C80, C87, C253, C254: 100n; C_0402b
C271, C272: DNP; C_0805b
F7, F8, F9, F10, F11, F12, F13, F14, F15, F16, F17, F18: Via; RF_via
FB11: BLM18PG181SN1D; C_0603b
R1, R2, R3, R4, R8, R9: 10; R_0402b
R5, R7, R10: 100; R_0402b
U6, U10, U11: PE42420; TFLGA-20

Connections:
3V3A_RX: C253.1, FB11.1; also elsewhere on the board
/A: C9.1, F10.1, F14.1; also elsewhere on the board
/B: C28.1, F8.1, F12.1; also elsewhere on the board
/RX1: C8.1, F9.1, F13.1; also elsewhere on the board
/RX2: C12.1, F7.1, F11.1; also elsewhere on the board
/RX_SW0: C36.2, R1.1; also elsewhere on the board
/RX_SW1: C35.2, R3.1; also elsewhere on the board
/RX_SW2: C77.2, R2.1; also elsewhere on the board
/RX_SW3: C54.2, R4.1; also elsewhere on the board
/RX_SW4: C84.2, R8.1; also elsewhere on the board
/RX_SW5: C83.2, R9.1; also elsewhere on the board
/receiver/RF_IN: U11.8 (RFC); also elsewhere on the board
/receiver/RX switch/3V3: C78.1, C80.1, C87.1, C254.1, C271.1, C272.1, FB11.2, R5.1, R7.1, R10.1
GND: C35.1, C36.1, C54.1, C77.1, C78.2, C80.2, C81.2, C82.2, C83.1, C84.1, C85.2, C87.2, C253.2, C254.2, C271.2, C272.2, F7.2, F8.2, F9.2, F10.2, F11.2, F12.2, F13.2, F14.2, F15.2, F16.2, F17.2, F18.2, U6.1 (GND), U6.2 (GND), U6.4 (GND), U6.5 (GND), U6.6 (GND), U6.7 (GND), U6.9 (GND), U6.10 (GND), U6.11 (GND), U6.12 (GND), U6.14 (GND), U6.15 (GND), U6.18 (GND), U6.19 (GND), U6.EP, U10.1 (GND), U10.2 (GND), U10.4 (GND), U10.5 (GND), U10.6 (GND), U10.7 (GND), U10.9 (GND), U10.10 (GND), U10.11 (GND), U10.12 (GND), U10.14 (GND), U10.15 (GND), U10.18 (GND), U10.19 (GND), U10.EP, U11.1 (GND), U11.2 (GND), U11.4 (GND), U11.5 (GND), U11.6 (GND), U11.7 (GND), U11.9 (GND), U11.10 (GND), U11.11 (GND), U11.12 (GND), U11.14 (GND), U11.15 (GND), U11.18 (GND), U11.19 (GND), U11.EP; also elsewhere on the board
unnamed: C8.2, U6.3 (RF1)
unnamed: C9.2, U6.13 (RF2)
unnamed: C12.2, U10.3 (RF1)
unnamed: C28.2, U10.13 (RF2)
unnamed: C81.1, R5.2, U6.20 (VDD)
unnamed: C82.1, R7.2, U10.20 (VDD)
unnamed: C85.1, R10.2, U11.20 (VDD)
unnamed: F15.1, F17.1, U6.8 (RFC), U11.3 (RF1)
unnamed: F16.1, F18.1, U10.8 (RFC), U11.13 (RF2)
unnamed: R1.2, U6.16 (CTRL2)
unnamed: R2.2, U10.16 (CTRL2)
unnamed: R3.2, U6.17 (CTRL1)
unnamed: R4.2, U10.17 (CTRL1)
unnamed: R8.2, U11.16 (CTRL2)
unnamed: R9.2, U11.17 (CTRL1)

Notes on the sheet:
PE4240 switch control truth table: CTRL1 CTRL2 RFC-RF1 RFC-RF2 Low Low Off Off Low High Off On High Low On Off High High N/A N/A
Port A1 A2 B1 B2 C1 C2 RF1 1 0 0 0 1 0 RF2 0 1 0 0 1 0 RF3 0 0 1 0 0 1 RF4 0 0 0 1 0 1

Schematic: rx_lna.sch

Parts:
C88: DNP; C_0805b
C89, C91: 100n; C_0402b
C90, C121: 1n; C_0402b
C113: 10u; C_0805b
C115: 10p; C_0402b
C120: 10n; C_0402b
C259: DNP; C_0402b
F5, F6: Via; RF_via
FB8: BLM18PG181SN1D; C_0603b
L1: AISC-0603HP-R10J; C_0603b
R14: 0; R_0402b
R21: 1.8; R_0603b
U12: TRF37A75; DFN-8-1EP_2x2mm_Pitch0.5mm

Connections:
/5V: C88.1, C89.1, FB8.1; also elsewhere on the board
/receiver/RF_BALUN: C121.1; also elsewhere on the board
/receiver/RF_IN: C90.2, F5.1, F6.1; also elsewhere on the board
GND: C88.2, C89.2, C91.2, C113.2, C115.2, C120.2, C259.1, F5.2, F6.2, R14.2, U12.3 (NC), U12.4 (NC), U12.6 (NC), U12.8 (NC), U12.9 (GND); also elsewhere on the board
unnamed: C90.1, U12.2 (RFIN)
unnamed: C91.1, C113.1, FB8.2, R21.1, U12.1 (VCC)
unnamed: C115.1, C120.1, L1.1, R21.2
unnamed: C121.2, C259.2, L1.2, U12.7 (RFOUT)
unnamed: R14.1, U12.5 (PWDN)

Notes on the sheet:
Gain: 11 - 13 dB
95 mA

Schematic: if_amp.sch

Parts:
C122, C123, C124, C125, C126, C127, C138: DNP; C_0402b
C128, C144, C146: 18p; C_0402b
C135, C154, C156: 100p; C_0402b
C139, C148, C149: 100n; C_0402b
C140: 36p; C_0402b
C155: 220p; C_0402b
C262: DNP; C_0805b
L3, L8: 1u; C_0603b
R22, R23, R24, R28: 0; R_0402b
R39: DNP; R_0402b
R40, R41, R42: 1k; R_0402b
R43, R44: 3.3k; R_0402b
R45, R46: 50; R_0402b
U21: ADA4940-1; VFQFN-16

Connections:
3V3A_RX: C148.1, C262.1, U21.5 (+VS), U21.6 (+VS), U21.7 (+VS), U21.8 (+VS), U21.12 (~DISABLE); also elsewhere on the board
/ADC+: C155.2, C156.1, R46.1; also elsewhere on the board
/ADC-: C154.2, C155.1, R45.1; also elsewhere on the board
/ADC_VCM: C149.1, U21.9 (VOCM); also elsewhere on the board
/receiver/DITHER: C139.2; also elsewhere on the board
/receiver/IF+: R23.2; also elsewhere on the board
/receiver/IF-: R22.2; also elsewhere on the board
GND: C122.1, C124.2, C125.1, C127.2, C138.2, C148.2, C149.2, C154.1, C156.2, C262.2, U21.13 (-VS), U21.14 (-VS), U21.15 (-VS), U21.16 (-VS), U21.EP; also elsewhere on the board
unnamed: C122.2, C123.1, R22.1, R24.2
unnamed: C123.2, C124.1, R23.1, R28.2
unnamed: C125.2, C126.1, C128.1, L3.1, R24.1
unnamed: C126.2, C127.1, C128.2, L8.1, R28.1
unnamed: C135.1, C140.2, L3.2, R41.2
unnamed: C135.2, C140.1, L8.2, R40.2
unnamed: C138.1, R39.2
unnamed: C139.1, R42.2
unnamed: C144.1, R43.1, U21.1 (-FB)
unnamed: C144.2, R39.1, R40.1, R43.2, U21.2 (+IN)
unnamed: C146.1, R44.1, U21.4 (+FB)
unnamed: C146.2, R41.1, R42.1, R44.2, U21.3 (-IN)
unnamed: R45.2, U21.10 (+OUT)
unnamed: R46.2, U21.11 (-OUT)

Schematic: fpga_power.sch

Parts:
C230, C231, C232, C233, C240, C241, C242, C243, C244, C245, C246, C247: 10u; C_0805b
C234, C235: 10n; C_0402b
C236: 36p; C_0402b
C237: 33p; C_0402b
C238: 16n; C_0402b
C239: 18n; C_0402b
D1, D4: SS13FL; SOD-123F
L9, L10: 33u (SRR6040A-330M); SRR6040A
R86: DNP; R_0402b
R87: 0; R_0402b
R96, R98: 68k; R_0402b
R99: 15k; R_0402b
R100: 16k; R_0402b
R101, R103: 4.99k; R_0402b
R102: 7.5k; R_0402b
R104: 2.5k; R_0402b
R105, R106: 33; R_0402b
U37, U38: L7980; DFN-8-1EP_3x3mm_Pitch0.5mm

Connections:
/1V0: C240.1, C243.1, C244.1, C246.1, L9.2, R101.1, R105.1; also elsewhere on the board
/1V8: C241.1, C242.1, C245.1, C247.1, L10.2, R103.1, R106.1; also elsewhere on the board
/5V: U37.3 (EN), U38.3 (EN); also elsewhere on the board
/power/12V: C230.1, C231.1, C232.1, C233.1, U37.8 (VCC), U38.8 (VCC); also elsewhere on the board
/power/SYNC_3V3: R86.2; also elsewhere on the board
/power/fpga_power/SYNC_1V0: R86.1, R87.2, U37.2 (SYNCH)
/power/fpga_power/SYNC_1V8: R87.1, U38.2 (SYNCH)
GND: C230.2, C231.2, C232.2, C233.2, C240.2, C241.2, C242.2, C243.2, C244.2, C245.2, C246.2, C247.2, D1.2 (A), D4.2 (A), R96.2, R98.2, R102.2, R104.2, U37.7 (GND), U37.9 (EP), U38.7 (GND), U38.9 (EP); also elsewhere on the board
unnamed: C234.1, R99.2
unnamed: C234.2, C236.2, C238.2, R101.2, R102.1, U37.5 (FB)
unnamed: C235.1, R100.2
unnamed: C235.2, C237.2, C239.2, R103.2, R104.1, U38.5 (FB)
unnamed: C236.1, R99.1, U37.4 (COMP)
unnamed: C237.1, R100.1, U38.4 (COMP)
unnamed: C238.1, R105.2
unnamed: C239.1, R106.2
unnamed: D1.1 (K), L9.1, U37.1 (OUT)
unnamed: D4.1 (K), L10.1, U38.1 (OUT)
unnamed: R96.1, U37.6 (FSW)
unnamed: R98.1, U38.6 (FSW)

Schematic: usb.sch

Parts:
C207, C210, C211, C212, C213, C214, C215: 100n; C_0402b
C208, C209: 33p; C_0402b
C263: DNP; C_0805b
FB12: BLM18PG181SN1D; C_0603b
R71: 4.7k; R_0402b
R72, R73: 10k; R_0402b
R79: 2k2; R_0402b
R80, R81: 27; R_0402b
R82: 1k5; R_0402b
R83: 470; R_0402b
R84, R85, R88: 33; R_0402b
U31: USB-MICRO; USB_MICRO
U32: 93LC46B; SOT-23-6
U33: FT2232D; LQFP-48_7x7mm_Pitch0.5mm
Y1: ABMM-6.000MHZ; ABMM

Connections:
/3V3D: C211.1, C212.1, U33.10 (SI/WUA), U33.14 (VCCIOA), U33.31 (VCCIOB); also elsewhere on the board
/5V: FB12.1; also elsewhere on the board
/fpga/FT_D0: U33.40 (BDBUS0); also elsewhere on the board
/fpga/FT_D1: U33.39 (BDBUS1); also elsewhere on the board
/fpga/FT_D2: U33.38 (BDBUS2); also elsewhere on the board
/fpga/FT_D3: U33.37 (BDBUS3); also elsewhere on the board
/fpga/FT_D4: U33.36 (BDBUS4); also elsewhere on the board
/fpga/FT_D5: U33.35 (BDBUS5); also elsewhere on the board
/fpga/FT_D6: U33.33 (BDBUS6); also elsewhere on the board
/fpga/FT_D7: U33.32 (BDBUS7); also elsewhere on the board
/fpga/RD#: U33.28 (BCBUS2/RD#); also elsewhere on the board
/fpga/RXF#: U33.30 (BCBUS0/RXF#); also elsewhere on the board
/fpga/SI/WUB: U33.26 (SI/WUB); also elsewhere on the board
/fpga/TCK: R84.1; also elsewhere on the board
/fpga/TDI: R88.1; also elsewhere on the board
/fpga/TDO: U33.22 (ADBUS2/TDO); also elsewhere on the board
/fpga/TMS: R85.1; also elsewhere on the board
/fpga/TXE#: U33.29 (BCBUS1/TXE#); also elsewhere on the board
/fpga/WR: U33.27 (BCBUS3/WR); also elsewhere on the board
/fpga/usb/5V: C207.1, C214.1, C215.1, C263.1, FB12.2, R73.1, R83.1, U32.6 (VCC), U33.3 (VCC), U33.42 (VCC)
/fpga/usb/DO: R73.2, R79.1, U32.1 (DO)
/fpga/usb/EECS: U32.5 (CS), U33.48 (EECS)
/fpga/usb/EEDATA: R79.2, U32.3 (DI), U33.2 (EEDATA)
/fpga/usb/EESK: U32.4 (CLK), U33.1 (EESK)
/fpga/usb/USBDM: R80.2, U31.2 (D-)
/fpga/usb/USBDP: R81.2, U31.3 (D+)
/fpga/usb/USB_5V: R71.1, U31.1 (VCC)
GND: C207.2, C208.2, C209.2, C210.2, C211.2, C212.2, C213.2, C214.2, C215.2, C263.2, R72.2, U31.5 (GND), U32.2 (VSS), U33.9 (GND), U33.18 (GND), U33.25 (GND), U33.34 (GND), U33.45 (AGND), U33.47 (TEST), Y1.2, Y1.4; also elsewhere on the board
unnamed: C208.1, U33.43 (XTIN), Y1.1
unnamed: C209.1, U33.44 (XTOUT), Y1.3
unnamed: C210.1, U33.6 (3V3OUT)
unnamed: C213.1, R83.2, U33.46 (AVCC)
unnamed: R71.2, R72.1, U33.4 (RESET#)
unnamed: R80.1, U33.8 (USBDM)
unnamed: R81.1, R82.1, U33.7 (USBDP)
unnamed: R82.2, U33.5 (RSTOUT#)
unnamed: R84.2, U33.24 (ADBUS0/TCK)
unnamed: R85.2, U33.21 (ADBUS3/TMS)
unnamed: R88.2, U33.23 (ADBUS1/TDI)

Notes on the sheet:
30 mA

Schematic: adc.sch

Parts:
C216, C220: 2.2u; C_0603b
C217, C218, C222, C249: 1u; C_0603b
C219, C221, C223, C224, C225: 100n; C_0402b
C248: 10u; C_0805b
R91, R93: 0; R_0402b
R92: DNP; R_0402b
U34: LTC2247; QFN-32-1EP_5x5mm_Pitch0.5mm
U39: LP5907-3V0; SOT-23-5

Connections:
/3V3D: C225.1, U34.21 (OVDD); also elsewhere on the board
/3V6: C248.1, U39.1 (IN), U39.3 (EN); also elsewhere on the board
/ADC+: U34.1 (AIN+); also elsewhere on the board
/ADC-: U34.2 (AIN-); also elsewhere on the board
/ADC_VCM: C216.1, C219.1, U34.31 (VCM); also elsewhere on the board
/CLK_ADC: U34.9 (CLK); also elsewhere on the board
/fpga/ADC_OE: U34.11 (~OE); also elsewhere on the board
/fpga/ADC_SHDN: U34.10 (SHDN); also elsewhere on the board
/fpga/D0: U34.12 (D0); also elsewhere on the board
/fpga/D1: U34.13 (D1); also elsewhere on the board
/fpga/D2: U34.14 (D2); also elsewhere on the board
/fpga/D3: U34.15 (D3); also elsewhere on the board
/fpga/D4: U34.16 (D4); also elsewhere on the board
/fpga/D5: U34.17 (D5); also elsewhere on the board
/fpga/D6: U34.18 (D6); also elsewhere on the board
/fpga/D7: U34.19 (D7); also elsewhere on the board
/fpga/D8: U34.22 (D8); also elsewhere on the board
/fpga/D9: U34.23 (D9); also elsewhere on the board
/fpga/D10: U34.24 (D10); also elsewhere on the board
/fpga/D11: U34.25 (D11); also elsewhere on the board
/fpga/D12: U34.26 (D12); also elsewhere on the board
/fpga/D13: U34.27 (D13); also elsewhere on the board
/fpga/OF: U34.28 (OF); also elsewhere on the board
/fpga/adc/3V0: C222.1, C223.1, C224.1, C249.1, R91.1, R93.2, U34.7 (VDD), U34.32 (VDD), U39.5 (OUT)
/fpga/adc/REFH: C217.1, C220.1, C221.1, U34.3 (REFH), U34.4 (REFH)
/fpga/adc/REFL: C218.1, C220.2, C221.2, U34.5 (REFL), U34.6 (REFL)
GND: C216.2, C217.2, C218.2, C219.2, C222.2, C223.2, C224.2, C225.2, C248.2, C249.2, R92.2, U34.8 (GND), U34.20 (OGND), U34.33 (GND), U39.2 (GND); also elsewhere on the board
unnamed: R91.2, R92.1, U34.29 (MODE)
unnamed: R93.1, U34.30 (SENSE)

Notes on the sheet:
50 mA

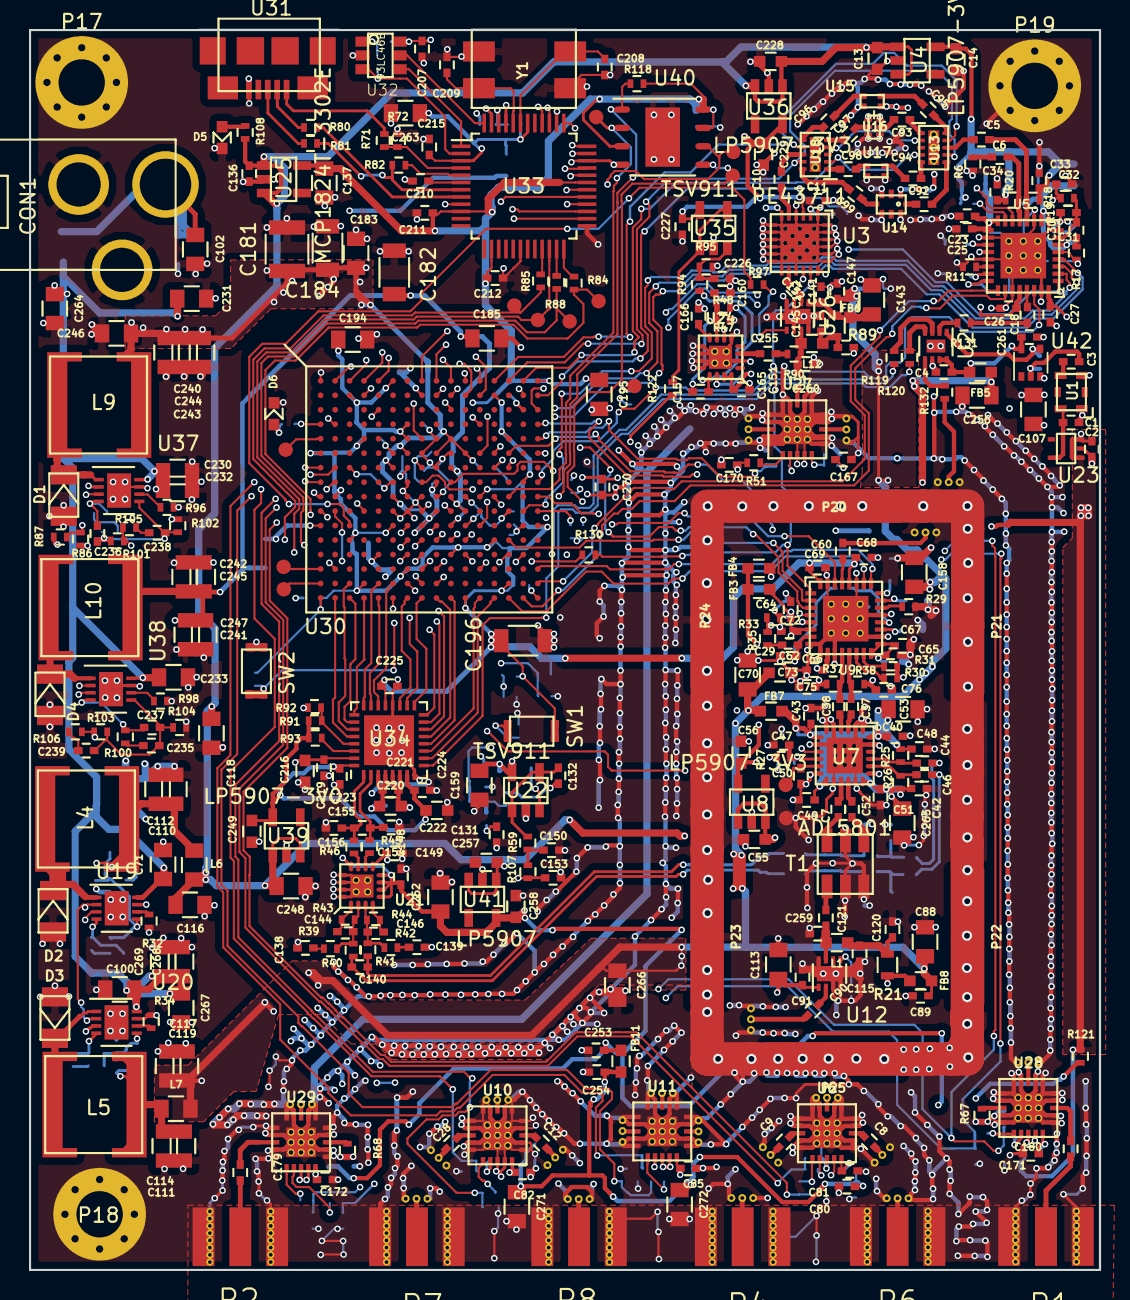
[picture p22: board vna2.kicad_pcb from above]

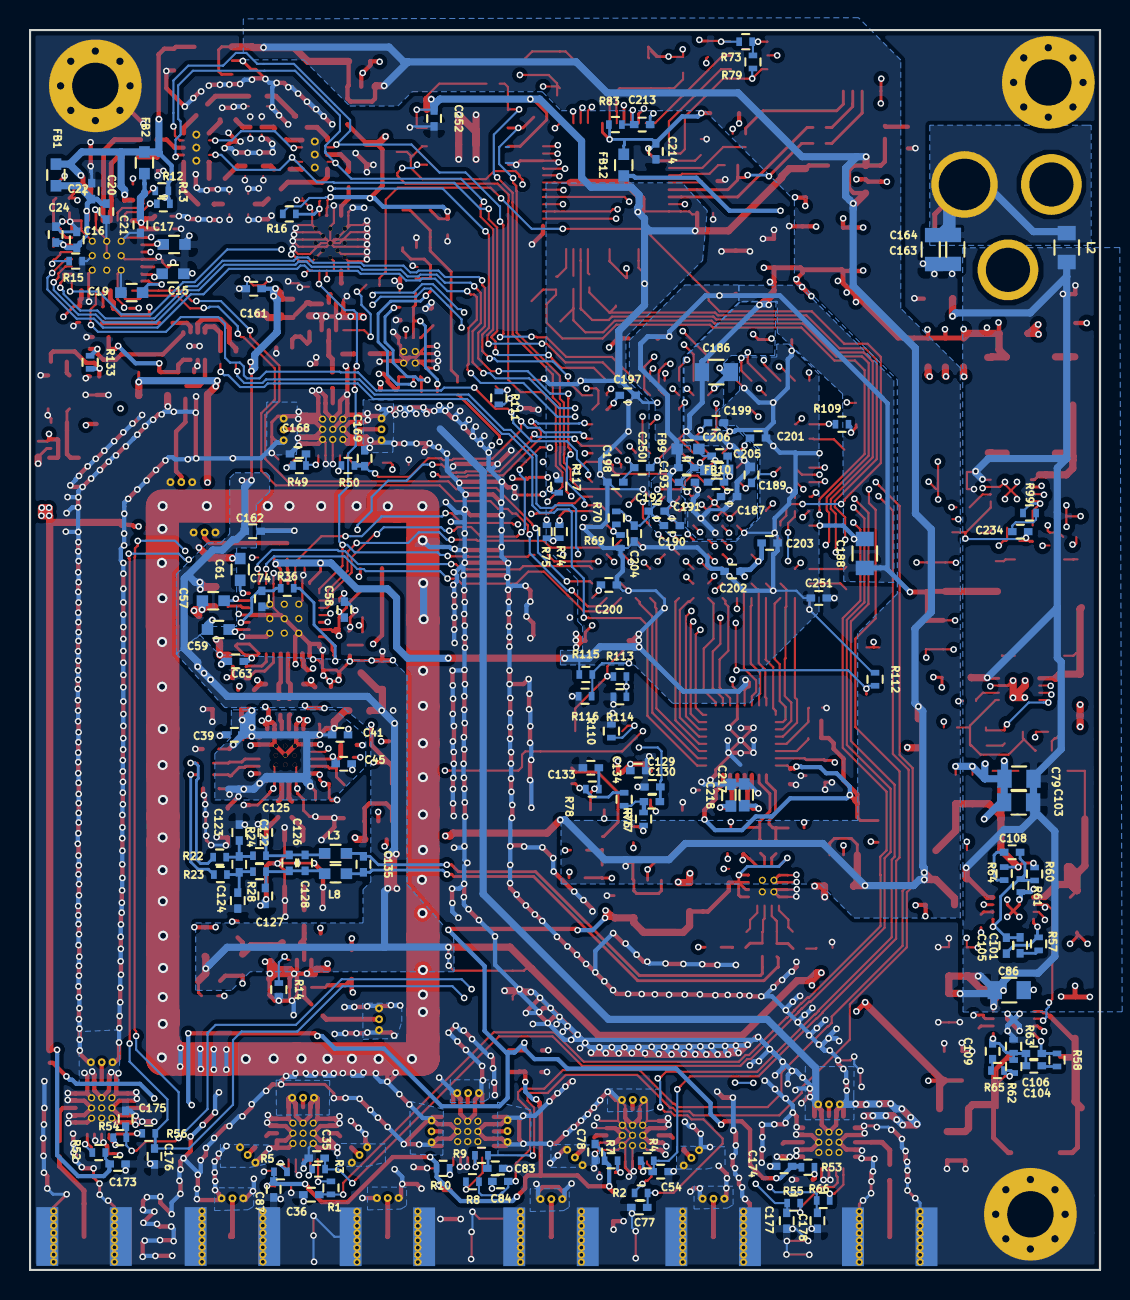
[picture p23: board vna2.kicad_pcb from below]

Board: 4 copper layers, 73.9 x 85.7 mm, 522 parts (148 on the bottom side), 310 nets.

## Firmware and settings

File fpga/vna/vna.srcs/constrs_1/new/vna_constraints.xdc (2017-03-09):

create_clock -period 25.000 -name clk -waveform {0.000 12.500} [get_ports clk]


set_property IOSTANDARD LVCMOS33 [get_ports {adc_in[12]}]
set_property IOSTANDARD LVCMOS33 [get_ports {adc_in[11]}]
set_property IOSTANDARD LVCMOS33 [get_ports {adc_in[10]}]
set_property IOSTANDARD LVCMOS33 [get_ports {adc_in[9]}]
set_property IOSTANDARD LVCMOS33 [get_ports {adc_in[8]}]
set_property IOSTANDARD LVCMOS33 [get_ports {adc_in[7]}]
set_property IOSTANDARD LVCMOS33 [get_ports {adc_in[6]}]
set_property IOSTANDARD LVCMOS33 [get_ports {adc_in[5]}]
set_property IOSTANDARD LVCMOS33 [get_ports {adc_in[4]}]
set_property IOSTANDARD LVCMOS33 [get_ports {adc_in[3]}]
set_property IOSTANDARD LVCMOS33 [get_ports {adc_in[2]}]
set_property IOSTANDARD LVCMOS33 [get_ports {adc_in[1]}]
set_property IOSTANDARD LVCMOS33 [get_ports {adc_in[0]}]
set_property IOSTANDARD LVCMOS33 [get_ports {adc_in[13]}]
set_property IOSTANDARD LVCMOS33 [get_ports clk]
set_property IOSTANDARD LVCMOS33 [get_ports {ft2232_data[7]}]
set_property IOSTANDARD LVCMOS33 [get_ports {ft2232_data[6]}]
set_property IOSTANDARD LVCMOS33 [get_ports {ft2232_data[5]}]
set_property IOSTANDARD LVCMOS33 [get_ports {ft2232_data[4]}]
set_property IOSTANDARD LVCMOS33 [get_ports {ft2232_data[3]}]
set_property IOSTANDARD LVCMOS33 [get_ports {ft2232_data[2]}]
set_property IOSTANDARD LVCMOS33 [get_ports {ft2232_data[1]}]
set_property IOSTANDARD LVCMOS33 [get_ports {ft2232_data[0]}]
set_property IOSTANDARD LVCMOS33 [get_ports {tx_filter[3]}]
set_property IOSTANDARD LVCMOS33 [get_ports {tx_filter[2]}]
set_property IOSTANDARD LVCMOS33 [get_ports {tx_filter[1]}]
set_property IOSTANDARD LVCMOS33 [get_ports {tx_filter[0]}]
set_property IOSTANDARD LVCMOS33 [get_ports {port_sw[1]}]
set_property IOSTANDARD LVCMOS33 [get_ports {port_sw[0]}]
set_property IOSTANDARD LVCMOS33 [get_ports {rx_sw[5]}]
set_property IOSTANDARD LVCMOS33 [get_ports {rx_sw[4]}]
set_property IOSTANDARD LVCMOS33 [get_ports {rx_sw[3]}]
set_property IOSTANDARD LVCMOS33 [get_ports {rx_sw[2]}]
set_property IOSTANDARD LVCMOS33 [get_ports {rx_sw[1]}]
set_property IOSTANDARD LVCMOS33 [get_ports {rx_sw[0]}]
set_property IOSTANDARD LVCMOS33 [get_ports dither]
set_property IOSTANDARD LVCMOS33 [get_ports rxf]
set_property IOSTANDARD LVCMOS33 [get_ports txe]
set_property IOSTANDARD LVCMOS33 [get_ports wr]
set_property IOSTANDARD LVCMOS33 [get_ports si_wu]
set_property IOSTANDARD LVCMOS33 [get_ports spi_clk]
set_property IOSTANDARD LVCMOS33 [get_ports lo_spi_data]
set_property IOSTANDARD LVCMOS33 [get_ports source_spi_data]
set_property IOSTANDARD LVCMOS33 [get_ports lo_le]
set_property IOSTANDARD LVCMOS33 [get_ports lo_ce]
set_property IOSTANDARD LVCMOS33 [get_ports source_le]
set_property IOSTANDARD LVCMOS33 [get_ports source_ce]
set_property IOSTANDARD LVCMOS33 [get_ports rd]
set_property IOSTANDARD LVCMOS33 [get_ports lo_rf_enable]
set_property IOSTANDARD LVCMOS33 [get_ports source_rf_enable]
set_property IOSTANDARD LVCMOS33 [get_ports atten_spi_data]
set_property IOSTANDARD LVCMOS33 [get_ports atten_le]
set_property IOSTANDARD LVCMOS33 [get_ports mixer_enable]
set_property IOSTANDARD LVCMOS33 [get_ports amp_pwdn]
set_property IOSTANDARD LVCMOS33 [get_ports lo_ld]
set_property IOSTANDARD LVCMOS33 [get_ports source_ld]
set_property IOSTANDARD LVCMOS33 [get_ports source_muxout]
set_property IOSTANDARD LVCMOS33 [get_ports lo_muxout]
set_property IOSTANDARD LVCMOS33 [get_ports led]
set_property IOSTANDARD LVCMOS33 [get_ports adc_of]
set_property IOSTANDARD LVCMOS33 [get_ports adc_oe]
set_property IOSTANDARD LVCMOS33 [get_ports adc_shdn]
set_property IOSTANDARD LVCMOS33 [get_ports xadc_vp]
set_property IOSTANDARD LVCMOS33 [get_ports xadc_vn]

set_property PACKAGE_PIN N11 [get_ports clk]
set_property PACKAGE_PIN T10 [get_ports {adc_in[0]}]
set_property PACKAGE_PIN T9 [get_ports {adc_in[1]}]
set_property PACKAGE_PIN P9 [get_ports {adc_in[2]}]
set_property PACKAGE_PIN P8 [get_ports {adc_in[3]}]
set_property PACKAGE_PIN R8 [get_ports {adc_in[4]}]
set_property PACKAGE_PIN T8 [get_ports {adc_in[5]}]
set_property PACKAGE_PIN R7 [get_ports {adc_in[6]}]
set_property PACKAGE_PIN T7 [get_ports {adc_in[7]}]
set_property PACKAGE_PIN R6 [get_ports {adc_in[8]}]
set_property PACKAGE_PIN T5 [get_ports {adc_in[9]}]
set_property PACKAGE_PIN R5 [get_ports {adc_in[10]}]
set_property PACKAGE_PIN T4 [get_ports {adc_in[11]}]
set_property PACKAGE_PIN T3 [get_ports {adc_in[12]}]
set_property PACKAGE_PIN R3 [get_ports {adc_in[13]}]
set_property PACKAGE_PIN T2 [get_ports adc_of]
set_property PACKAGE_PIN T12 [get_ports adc_oe]
set_property PACKAGE_PIN T13 [get_ports adc_shdn]

set_property PACKAGE_PIN A13 [get_ports {tx_filter[3]}]
set_property PACKAGE_PIN A14 [get_ports {tx_filter[2]}]
set_property PACKAGE_PIN B16 [get_ports {tx_filter[1]}]
set_property PACKAGE_PIN A15 [get_ports {tx_filter[0]}]

set_property PACKAGE_PIN D16 [get_ports {port_sw[1]}]
set_property PACKAGE_PIN E16 [get_ports {port_sw[0]}]
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

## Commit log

2017-03-21 Add coupler design files
    [rf_bridge_Bottom.gbl, rf_bridge_Mask.gts, rf_bridge_Mask_bottom.gbs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]
2017-05-06 Update PC code
    Add switch terms. Tune PLL registers. Don't write unnecessary values.
2017-05-26 Add send immediate pin logic for FT2232D
    When last byte of the IQ packet has been sent to the FT2232D toggle
    SI_WU pin to immediately initiate USB transfer to host.
2017-07-27 Update components values
    Change IF amplifier to ADA4940. Same footprint, no changes in PCB.
    Fix M[0:2] connections.
    [fpga.sch, if_amp.sch, transmitter.sch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]
2017-07-27 Add openocd scripts for programming FPGA and SPI flash
    [interface.cfg, program_flash.cfg, program_fpga.cfg]
2018-01-28 Fix ferrite bead amounts in coupler BOM
